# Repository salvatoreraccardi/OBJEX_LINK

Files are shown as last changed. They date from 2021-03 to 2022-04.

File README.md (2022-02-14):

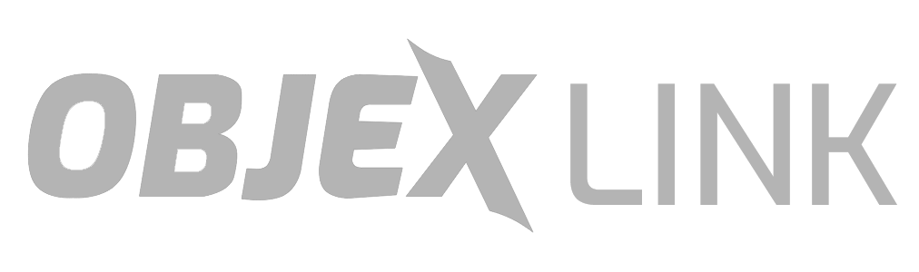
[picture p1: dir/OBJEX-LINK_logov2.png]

# OBJEX Link 

**OBJEX Link website:** https://objex.link/

**OBJEX Link Docs:** https://docs.objex.link/

**email:** info@objex.link 

**OBJEX Link Shop:** https://www.tindie.com/stores/objex/





**Youtube:** <br />
Project introduction - **OBJEX Link** [watch the video](https://www.youtube.com/watch?v=X29LyX-1ozA)

Assembly and testing - **Protoboard&Socket_v2.0** [watch the video](https://www.youtube.com/watch?v=N7MFNUX0_PA)

Assembly and testing - **OBJEX Link v1.6-C3:** [watch the video](https://www.youtube.com/watch?v=o9e5-9o4egI)

Assembly and testing - **OBJEX Link v1.6:** [watch the video](https://www.youtube.com/watch?v=haHsvLIlmms)

Assembly and testing - **OBJEX Link v1.5:** [watch the video](https://www.youtube.com/watch?v=wx3dR2j1C28)

Assembly and testing - **OBJEX Link v1.0:** [watch the video](https://www.youtube.com/watch?v=_4CofqktS38)

## What is OBJEX Link?
OBJEX Link is a modular IoT board. It is designed to develop **IoT devices** that are **easy to repair** and **recycle**. OBJEX Link is designed to meet a wide range of uses: **Smart Home & Cities, IIOT, Everyday things & Wearables, Predictive Maintenance, Agriculture Automation.**

OBJEX Link can also be used for **rapid prototyping, and developing research and robotics projects, with the right module you can extend the possible uses of the board.**

The compact form factor and board design ensure easy use and maintenance of the board. The architecture of OBJEX Link is composed of two parts, the first is the mainboard (OBJEX Link) and the second is the module allows for easy customization and interfacing with hardware compared to other IoT boards.

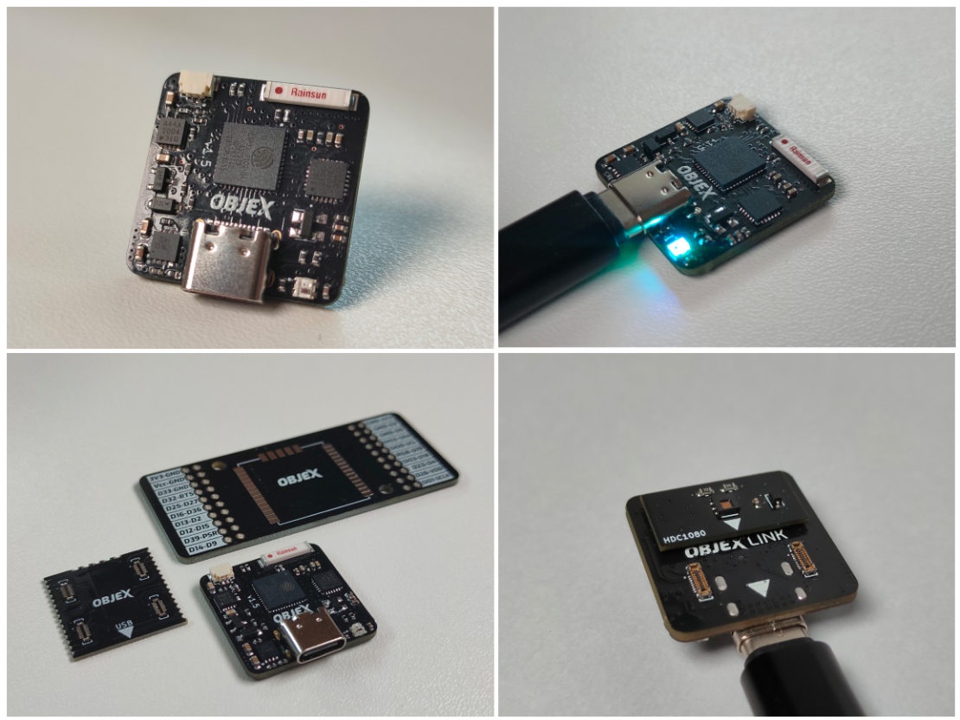
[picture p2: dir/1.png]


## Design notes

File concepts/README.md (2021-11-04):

# Concepts/Prototypes based on OBJEX Link

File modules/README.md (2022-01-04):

# OBJEX Modules
Modules are an essential element of OBJEX Link. In fact, they are the modules that allow OBJEX Link to detect the temperature, control an motor etc - *(like Arduino shields but smaller and more compact)*.

**Here are some features/components you can add with modules:**
- Sensors
- Relay 
- Motor driver(Stepper Motor, DC, LRA, ERM).
- OLED Display
- Convert slimstack connectors to larger connectors (type 2.54mm pitch connectors).
- A specific circuit (such as LoRa Module, PSRAM, PWM controller, etc).

## Types of modules
There are several form formats to ensure maximum customization.

| Type | Description | Size | PCB thickness | Connector | Connector Type | 3V3 | 5V | A |
|---|---|---|---|---|---|-----|----|---|
| M0 | Standard Module | 10x20mm | 0.8mm | 2 |  BM28B0 |  ✓ |  ✓  | 5 |
| M1 | Standard Module | 20x20mm | 0.8mm | 4 |  BM28B0 |  ✓ |  ✓  | 5 |
| M1E | With I2C EEPROM | 20x20mm | 0.8mm | 4 |  BM28B0 |  ✓ |  ✓  | 5 |

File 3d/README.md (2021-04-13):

## *NOTICE!*
**OBJEX Link is under development and optimization so some project files may vary over time.**

# OBJEX Modules
Modules are an essential element of OBJEX Link. In fact, they are the modules that allow OBJEX Link to detect the temperature, control an motor etc - *(like Arduino shields but smaller and more compact)*.

**Here are some features/components you can add with modules:**

- Sensors
- Relay 
- Motor driver(Stepper Motor, DC, LRA, ERM).
- OLED Display
- Convert slimstack connectors to larger connectors (type 2.54mm pitch connectors).
- A specific circuit (such as LoRa Module, PSRAM, PWM controller, etc).

## Types of modules
There are several form formats to ensure maximum customization.

| Type | Description | Size | PCB thickness | Connector | Connector Type | 3V3 | 5V | A |
|---|---|---|---|---|---|-----|----|---|
| M0 | Standard Module | 10x20mm | 0.8mm | 2 |  BM28B0 |  ✓ |  ✓  | 5 |
| M1 | Standard Module | 20x20mm | 0.8mm | 4 |  BM28B0 |  ✓ |  ✓  | 5 |

## List of available modules

| Module Type | Module Name | Description | Size | Version | Designer | Buy | Example of use  |
|---|---|---|---|---|---|---|---|
| M1 | Button | Button with 4 leds | 20x20mm | 1.0 | Salvatore Raccardi | Not available | IoT Button|
| M0 | MPU6050 | Sensor - Gyroscope| 10x20mm | 1.0 | Salvatore Raccardi | Not available | - |
| M0 | HDC1080 | Sensor - Temperature/Humidity| 10x20mm | 1.0 | Salvatore Raccardi | Not available | Weather station |

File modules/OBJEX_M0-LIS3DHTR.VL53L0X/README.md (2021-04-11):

## COPYRIGHT
Copyright CERN 2020.

This source describes Open Hardware and is licensed under the CERN-OHLW v2

You may redistribute and modify this documentation and make products
using it under the terms of the CERN-OHL-W v2 (https:/cern.ch/cern-ohl).
This documentation is distributed WITHOUT ANY EXPRESS OR IMPLIED
WARRANTY, INCLUDING OF MERCHANTABILITY, SATISFACTORY QUALITY
AND FITNESS FOR A PARTICULAR PURPOSE. Please see the CERN-OHL-W v2
for applicable conditions.

Source location: https://www.ohwr.org/project/wr-switch-hw

As per CERN-OHL-W v2 section 4.1, should You produce hardware based on
these sources, You must maintain the Source Location visible on the
external case of the White Rabbit switch or other product you make using
this documentation.

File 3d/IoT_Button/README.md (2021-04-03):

# OBJEX Link - 3D Case
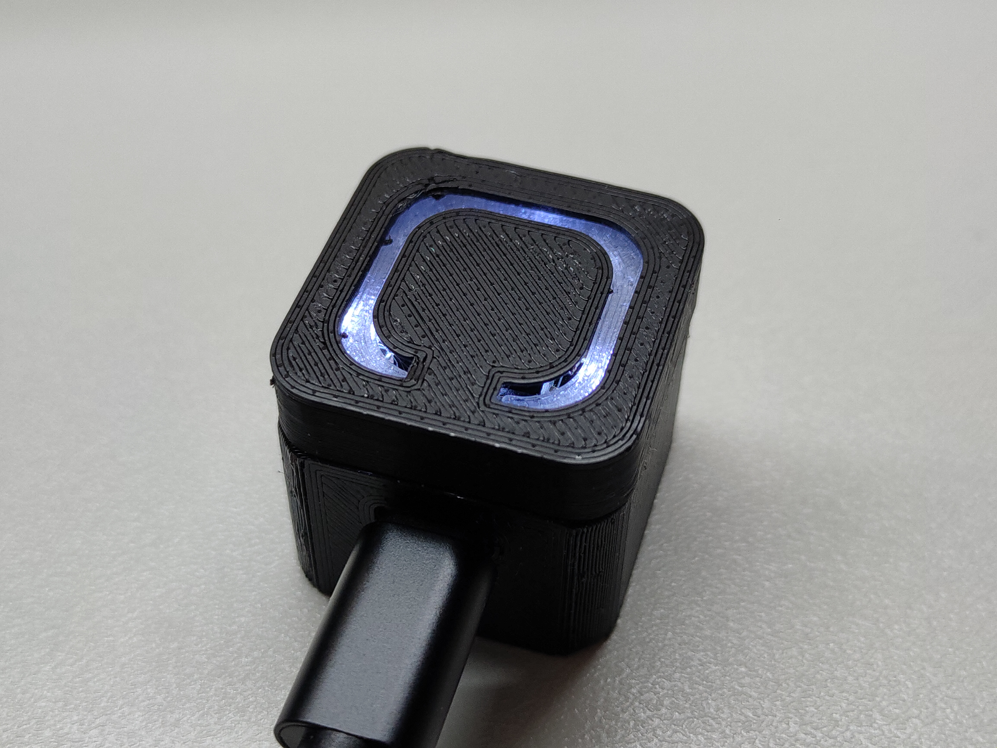
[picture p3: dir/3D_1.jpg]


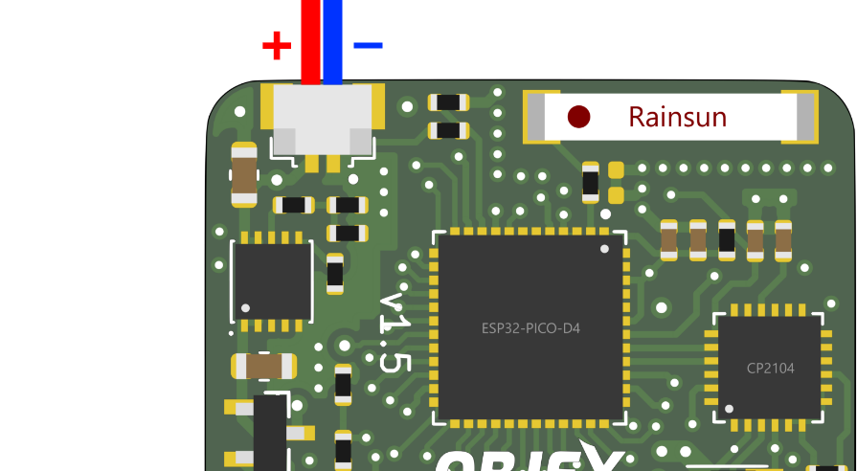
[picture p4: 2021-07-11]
dir/pinout_2.png

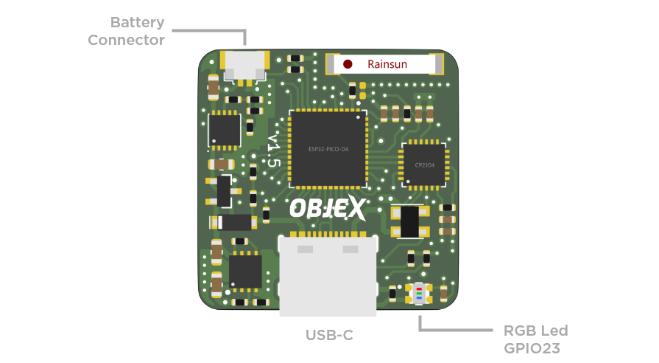
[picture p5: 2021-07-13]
dir/pinout1.png

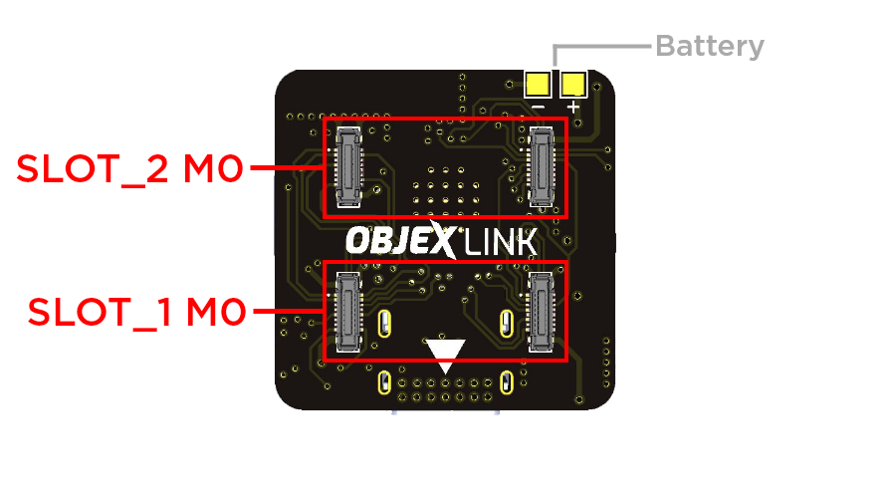
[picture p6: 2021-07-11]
dir/pinout_3.png

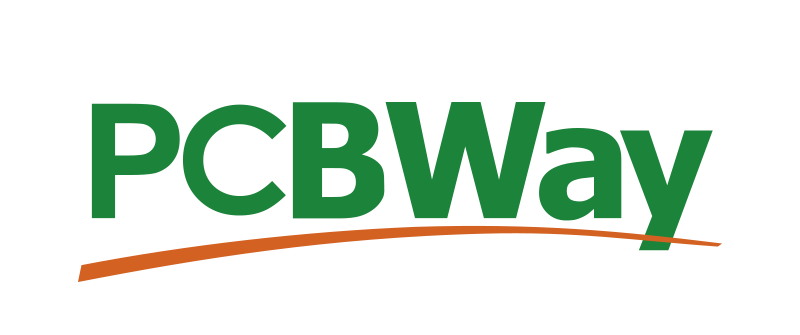
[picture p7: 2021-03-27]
dir/pcbway.png

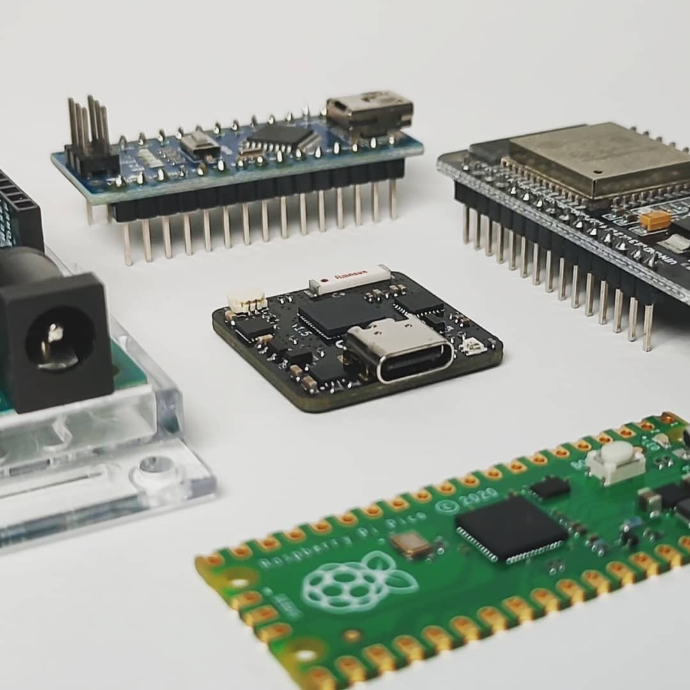
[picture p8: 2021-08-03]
dir/OBJEXLinkvsboards.jpg

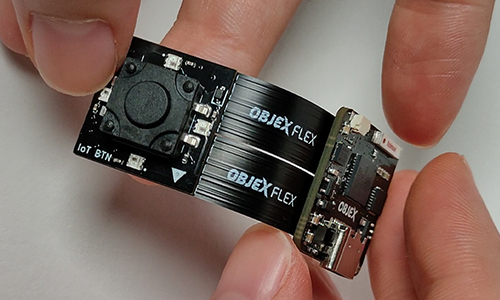
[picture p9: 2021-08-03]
dir/Flex_6.jpg

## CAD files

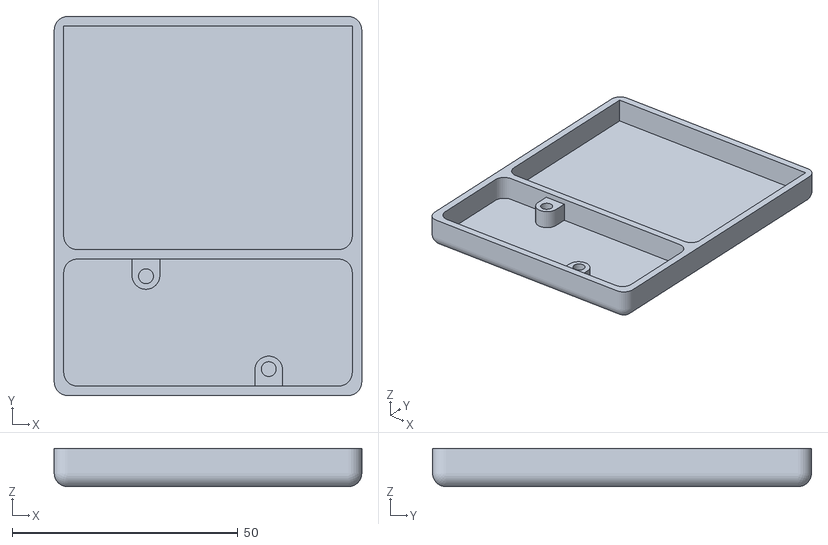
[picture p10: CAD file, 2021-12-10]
3d/Cover_2.54Board-v2.0/OBJEXLink_Cover_Pro.stl
68.1 x 83.9 x 8.50

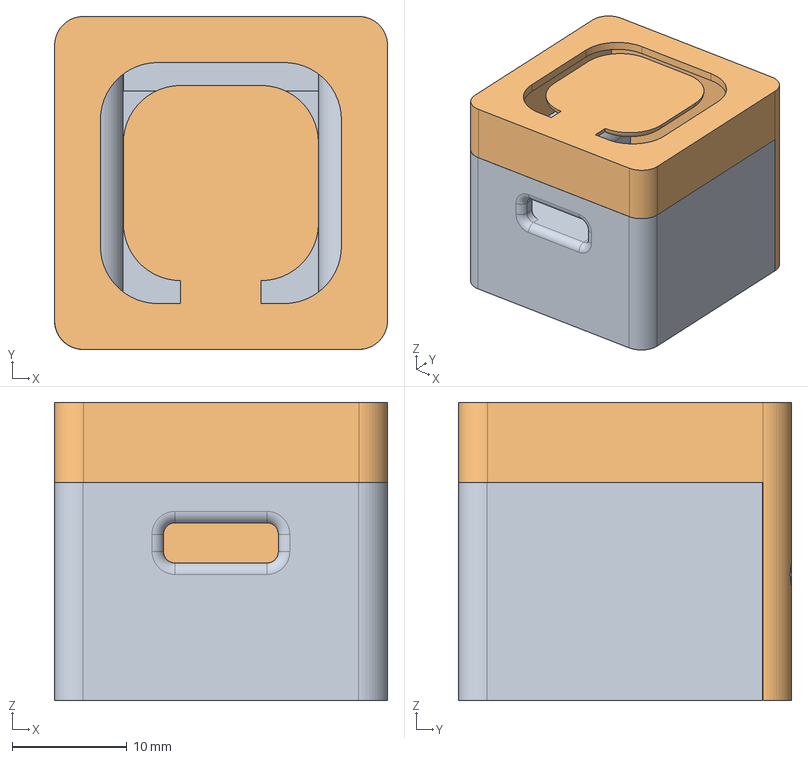
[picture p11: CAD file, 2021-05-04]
3d/IoT_Button/beta-2.0/OBJEX_LINK-IoT_Btn.step
29.0 x 29.0 x 26.0 mm

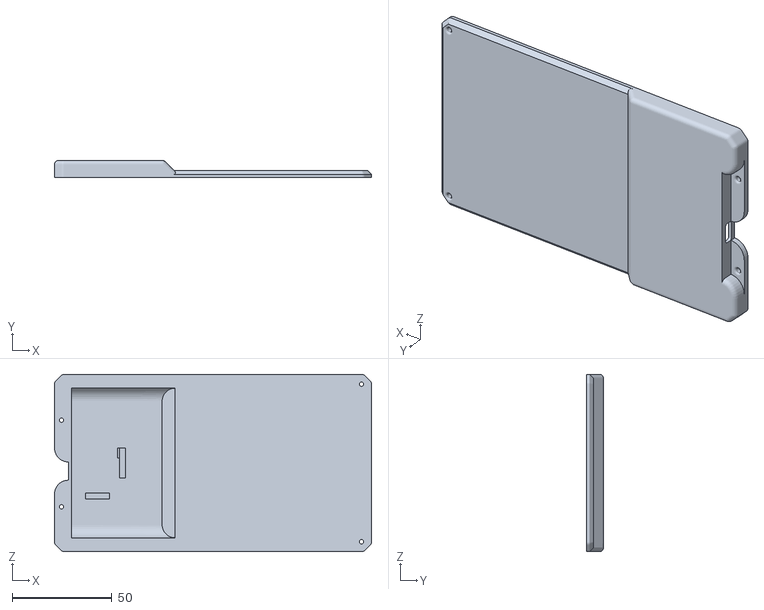
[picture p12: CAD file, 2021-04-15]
3d/Led_Spotlight-v1.0/Back Cover.stl
159.0 x 8.50 x 89.0

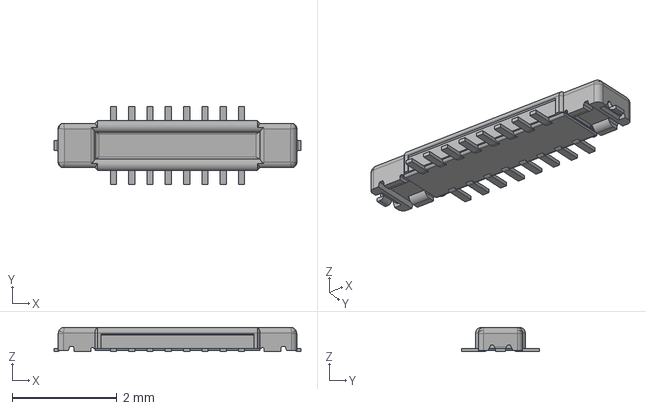
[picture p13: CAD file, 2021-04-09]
KiCad_lib/SlimStack Connector/BM28-16DP.stp
4.72 x 1.50 x 0.465 mm

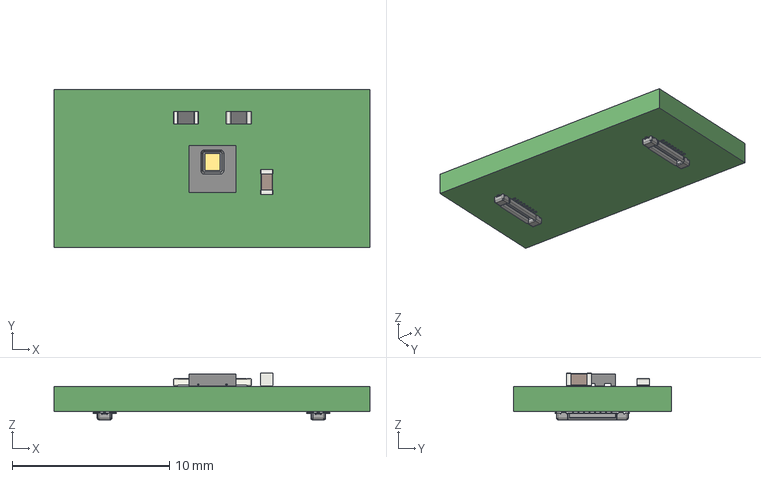
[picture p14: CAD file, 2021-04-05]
modules/OBJEX_M0-HDC1080/OBJEX_M0-HDC1080.step
20.1 x 10.0 x 2.97 mm

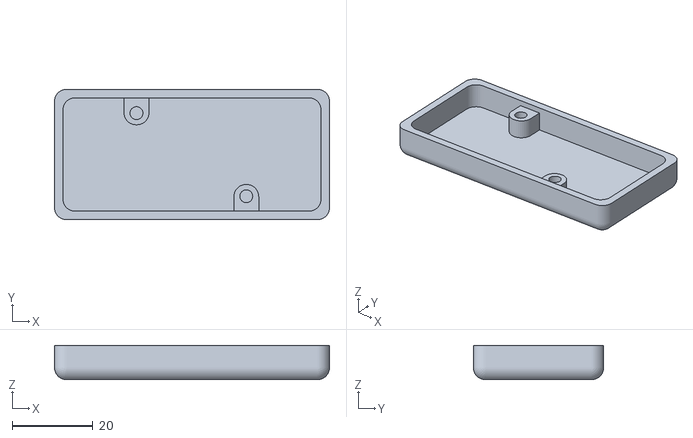
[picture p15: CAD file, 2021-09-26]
3d/Cover_2.54Board-v2.0/V2.1coverOBJEXLink.stl
68.1 x 32.3 x 8.50

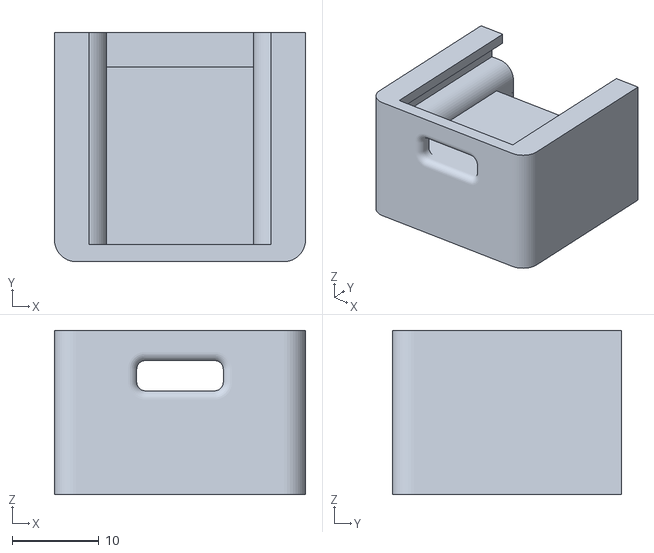
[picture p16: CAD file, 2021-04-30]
3d/IoT_Button/beta-2.0/Master.stl
29.0 x 26.5 x 19.0

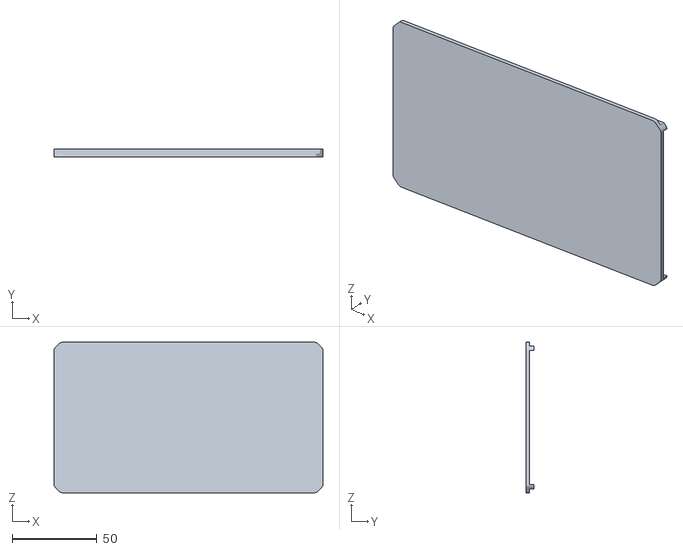
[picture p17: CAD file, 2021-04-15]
3d/Led_Spotlight-v1.0/Lux-Plate.stl
159.0 x 4.60 x 89.0

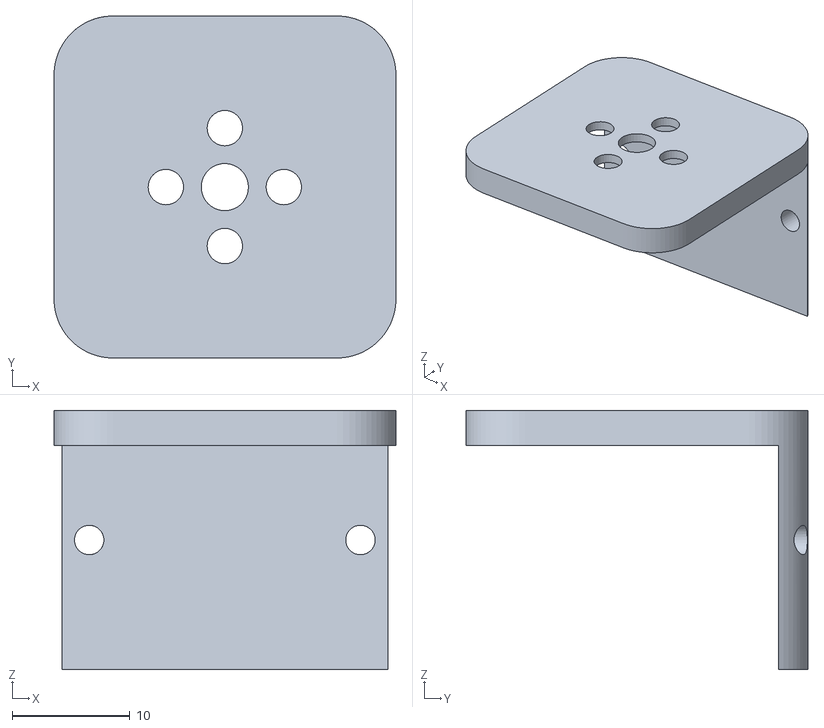
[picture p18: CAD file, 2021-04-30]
3d/IoT_Button/beta-2.0/HDC1080-Top.stl
29.0 x 29.0 x 22.0

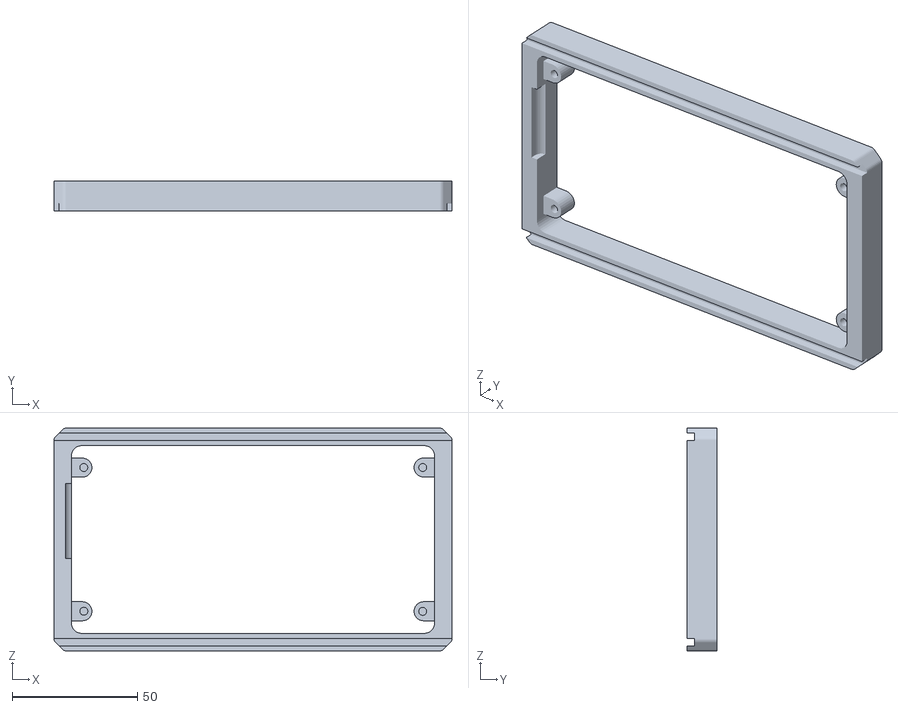
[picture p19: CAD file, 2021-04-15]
3d/Led_Spotlight-v1.0/Frame.stl
159.0 x 12.0 x 89.0

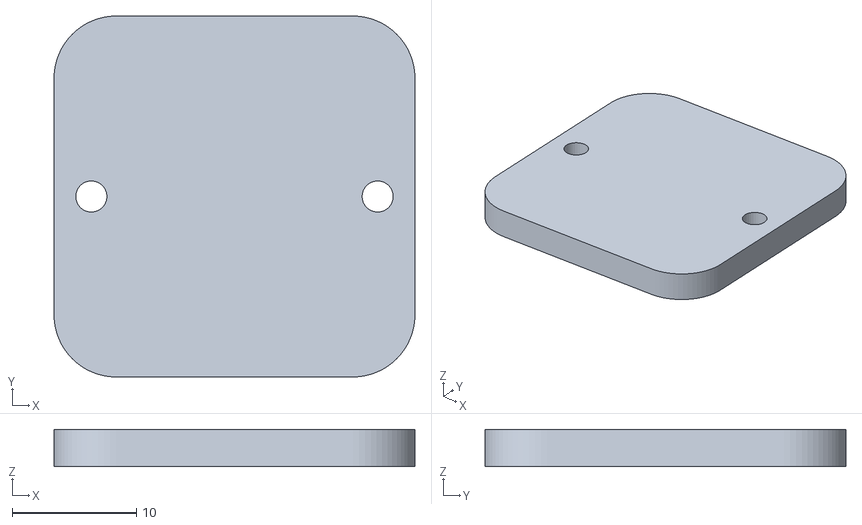
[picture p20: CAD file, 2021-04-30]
3d/IoT_Button/beta-2.0/Bottom.stl
29.0 x 29.0 x 3.00

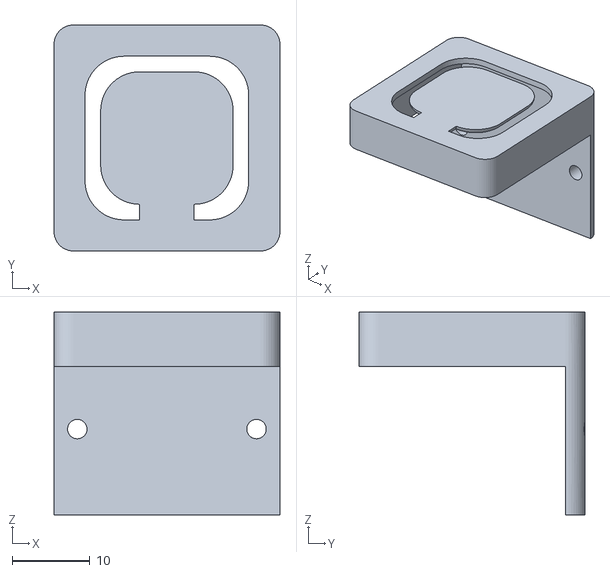
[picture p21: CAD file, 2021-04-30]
3d/IoT_Button/beta-2.0/BTN-Top.stl
29.0 x 29.0 x 26.0

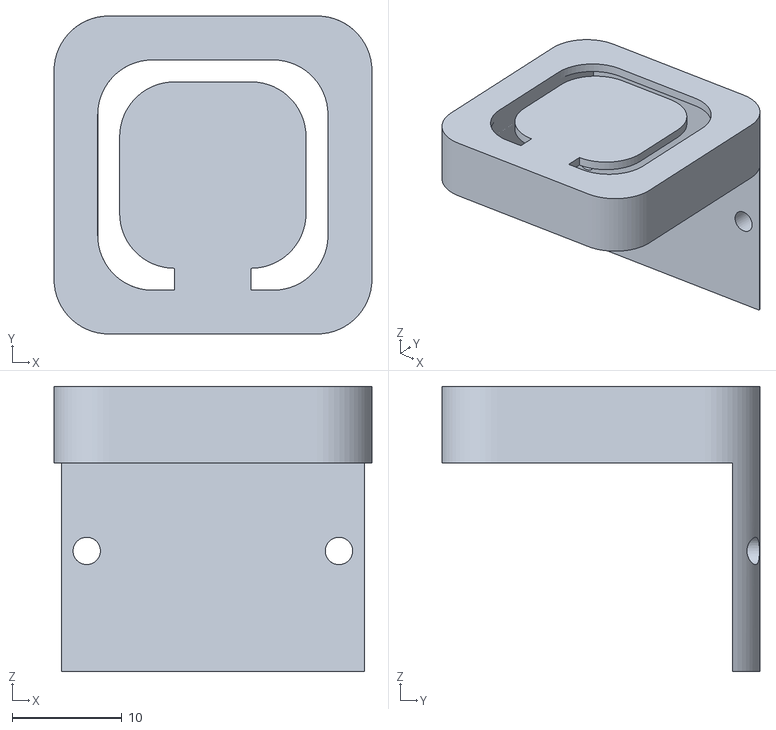
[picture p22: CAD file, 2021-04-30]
3d/IoT_Button/beta-2.0/Top.stl
29.0 x 29.0 x 26.0

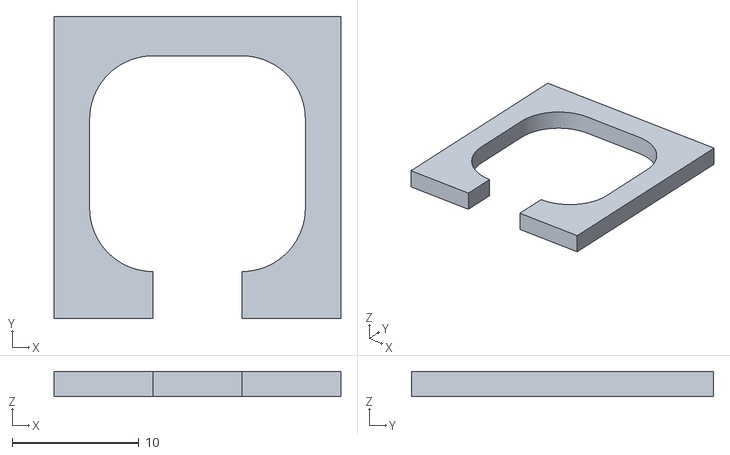
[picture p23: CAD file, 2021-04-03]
3d/IoT_Button/beta-2.0/Top_Glass.stl
22.6 x 23.8 x 2.00

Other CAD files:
3d/Cover_2.54Board-v2.0/V2coverOBJEXLink.stl
3d/IoT_Button/beta-1.0/Master.stl
3d/IoT_Button/beta-1.0/HDC1080-Top.stl
3d/IoT_Button/beta-1.0/BTN-Top.stl

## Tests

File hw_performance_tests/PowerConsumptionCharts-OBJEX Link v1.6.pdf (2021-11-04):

# Power Consumption Charts

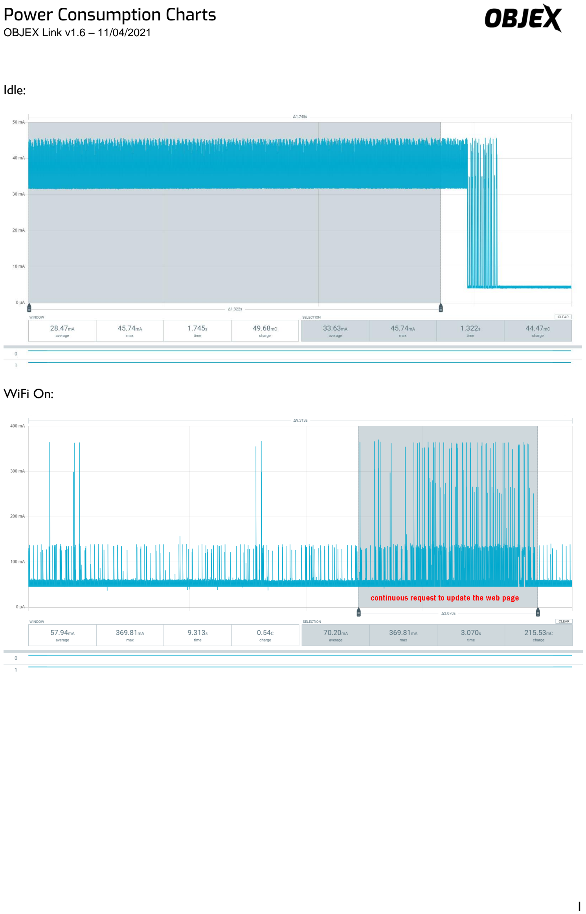
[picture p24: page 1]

OBJEX Link v1.6 – 11/04/2021

Idle:

WiFi On:

Bluetooth On:

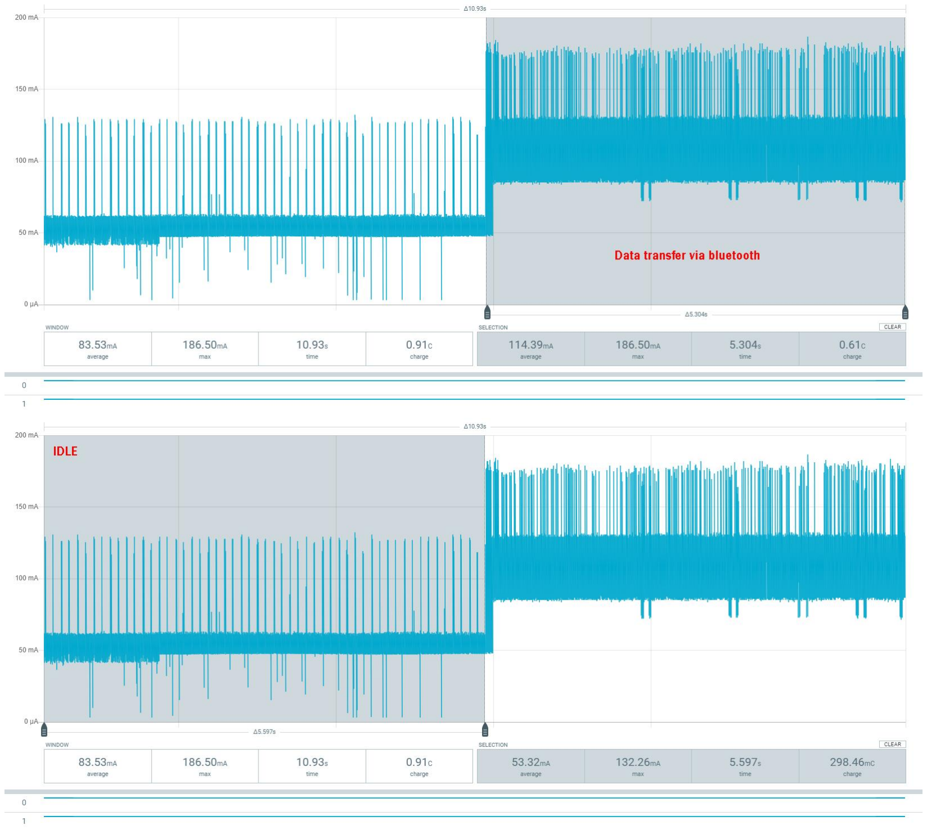
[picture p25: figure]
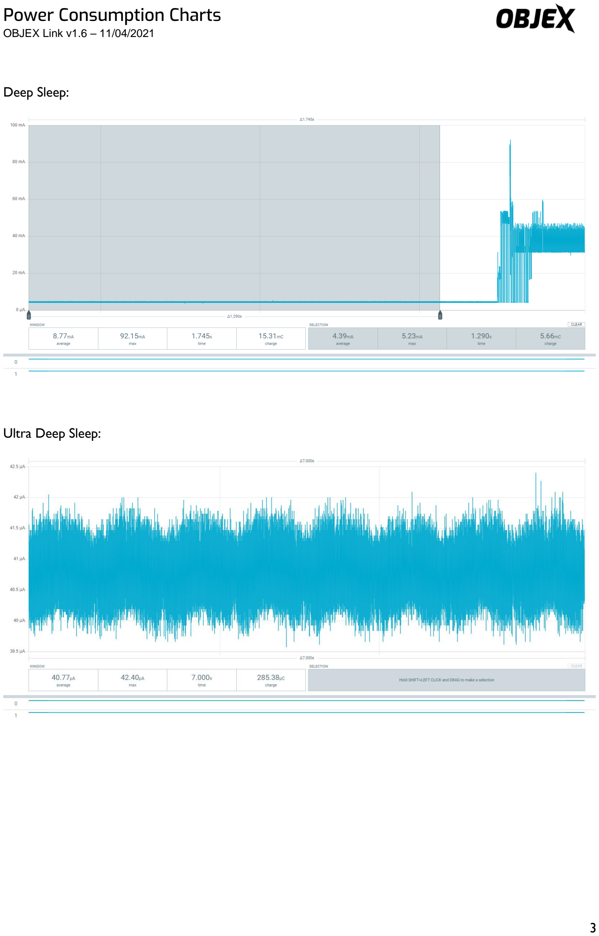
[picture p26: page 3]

Deep Sleep:

Ultra Deep Sleep:

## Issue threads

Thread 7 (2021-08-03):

Broken Trello link

zaosoula, 2021-08-03:
Hello, the Trello link in the footer of the wiki is broken

salvatoreraccardi, 2021-08-03:
Yes, you are right, I am fixing the board on Trello. I'll let you know when it's available.

Closed 2021-08-03.

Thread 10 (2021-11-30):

native USB

Aightech, 2021-11-30:
Hi there,
Thank you very much for sharing your great work on github!

I looked at your OBJEX Link v1.6-C3 RISC-V schematics and I realised you were using a cp2102 for the USB communication. Is there a particular reason you did not use the native USB of the esp32-C3 ?

Thanks again!

salvatoreraccardi, 2021-11-30:
@Aightech Hi, thank you for your question. I have already designed v1.7-C3 without the CP2102N and some improvements. Next week I will get the PCBs delivered👍

Aightech, 2021-12-01:
Wonderful, can't wait to see it then! 😁

salvatoreraccardi, 2021-12-29:
https://github.com/salvatoreraccardi/OBJEX_LINK/tree/main/boards/OBJEX_LINK-Rev1.7-C3_RISC-V

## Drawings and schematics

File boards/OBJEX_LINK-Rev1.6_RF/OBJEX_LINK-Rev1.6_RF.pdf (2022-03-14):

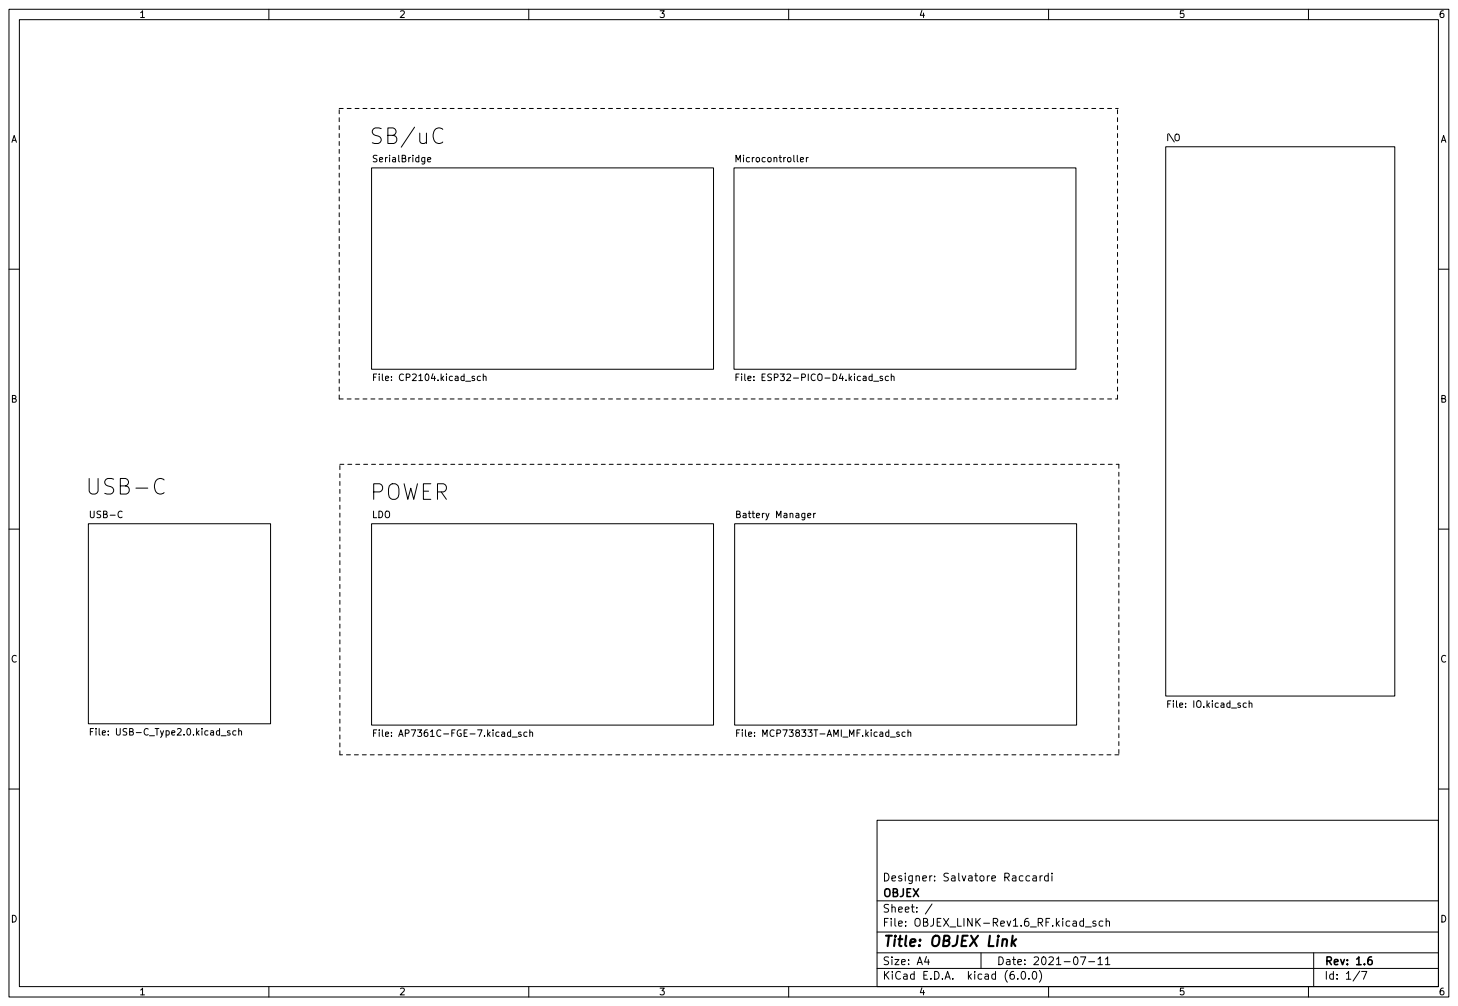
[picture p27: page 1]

Microcontroller File: ESP32-PICO-D4.kicad_sch SerialBridge File: CP2104.kicad_sch

File: OBJEX_LINK-Rev1.6_RF.kicad_sch Sheet: / OBJEX Designer: Salvatore Raccardi

Id: 1/7 Title: OBJEX Link

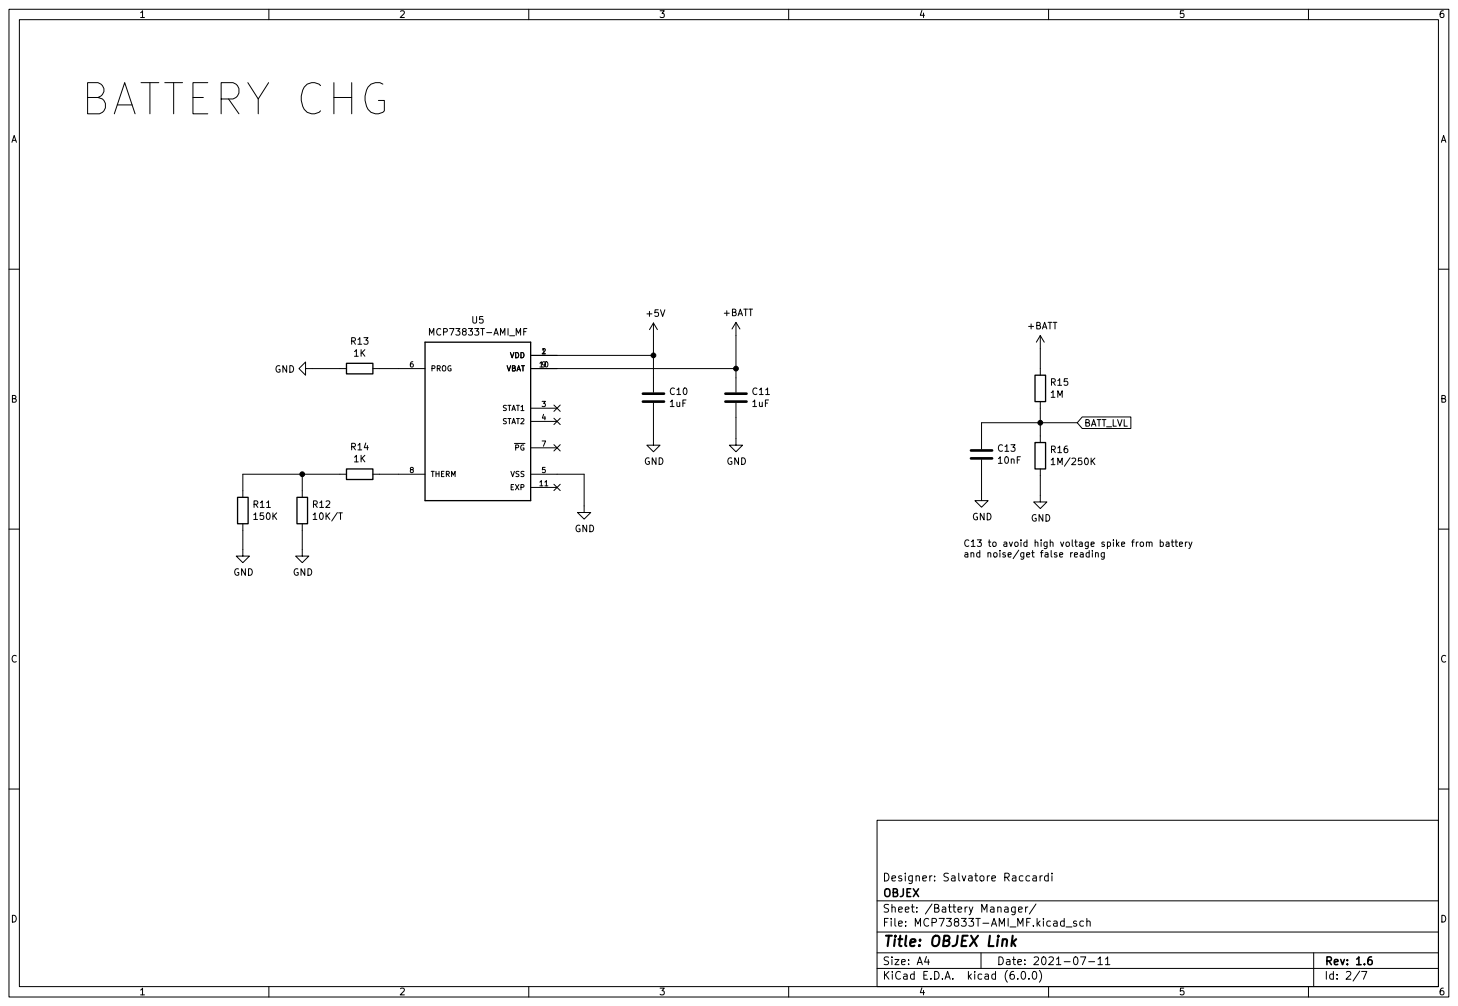
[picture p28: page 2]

BATT_LVL C13 to avoid high voltage spike from battery

and noise/get false reading

File: MCP73833T-AMI_MF.kicad_sch
Id: 2/7 Title: OBJEX Link

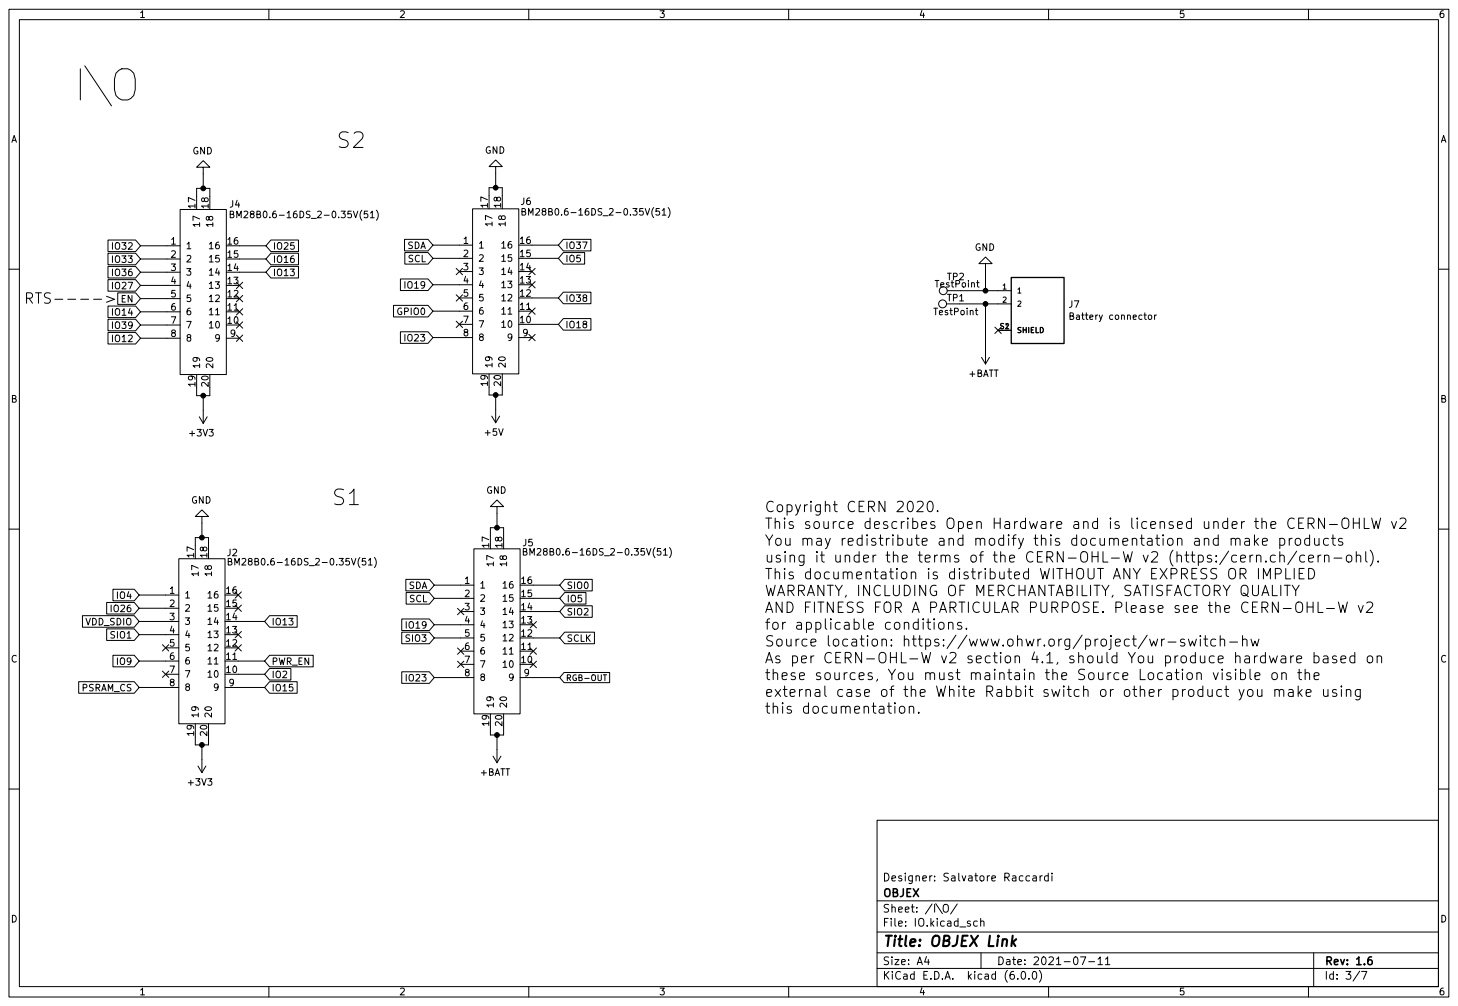
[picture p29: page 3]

Copyright CERN 2020.
This source describes Open Hardware and is licensed under the CERN-OHLW v2
You may redistribute and modify this documentation and make products
using it under the terms of the CERN-OHL-W v2 (https:/cern.ch/cern-ohl).
This documentation is distributed WITHOUT ANY EXPRESS OR IMPLIED
WARRANTY, INCLUDING OF MERCHANTABILITY, SATISFACTORY QUALITY
AND FITNESS FOR A PARTICULAR PURPOSE. Please see the CERN-OHL-W v2
for applicable conditions.
Source location: https://www.ohwr.org/project/wr-switch-hw
As per CERN-OHL-W v2 section 4.1, should You produce hardware based on
these sources, You must maintain the Source Location visible on the
external case of the White Rabbit switch or other product you make using
this documentation.

Id: 3/7 Title: OBJEX Link

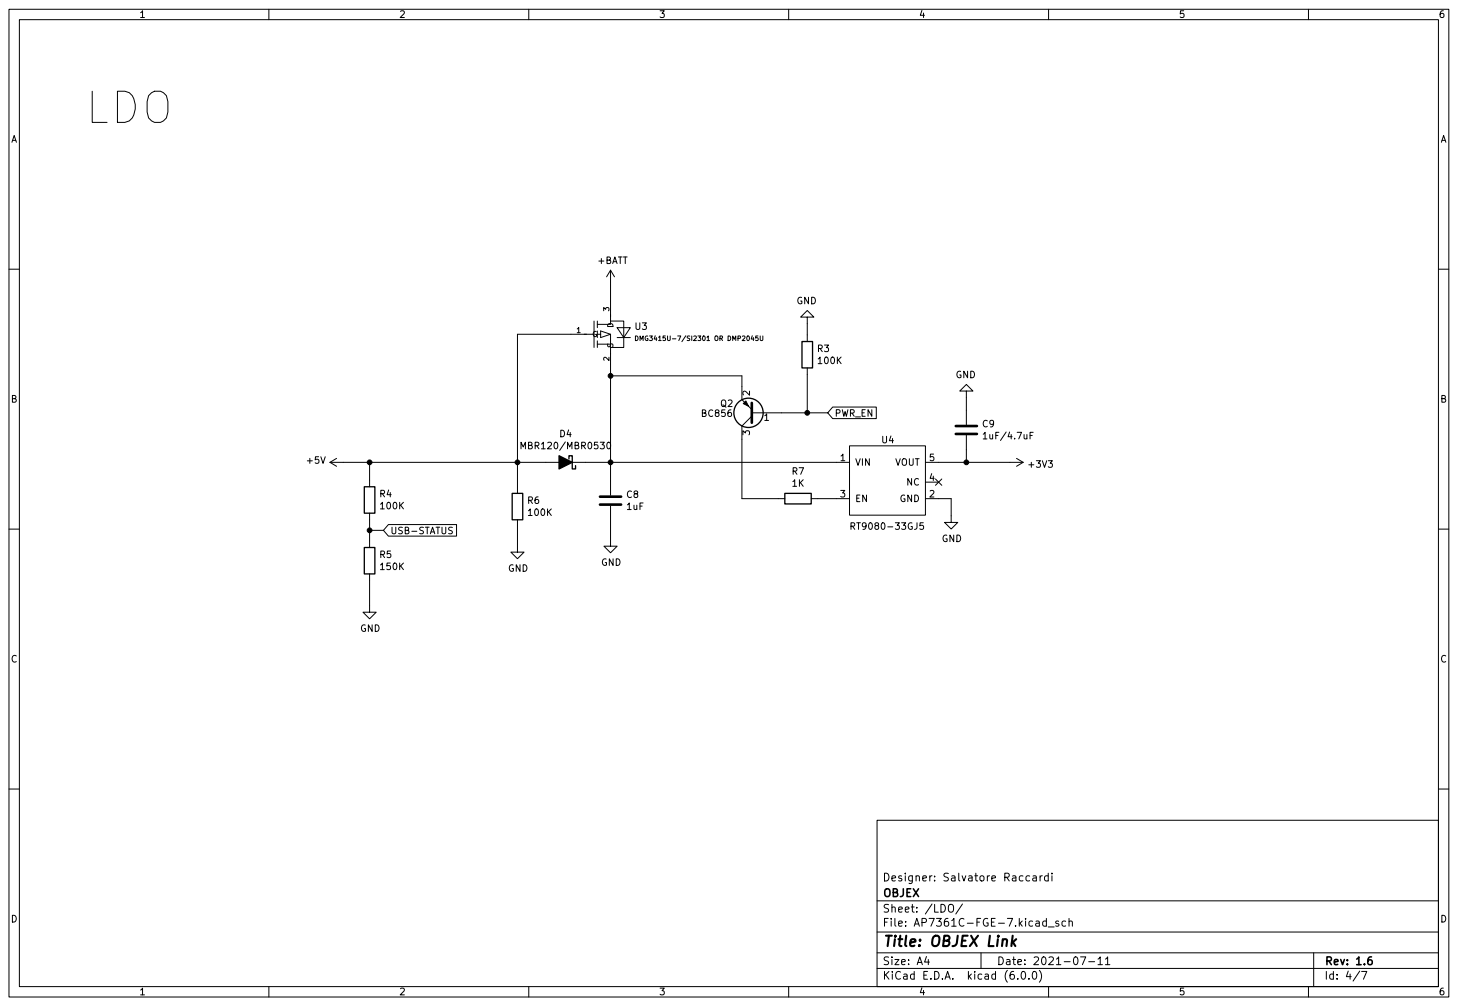
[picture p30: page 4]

File: AP7361C-FGE-7.kicad_sch Sheet: /LDO/ OBJEX Designer: Salvatore Raccardi

Id: 4/7 Title: OBJEX Link

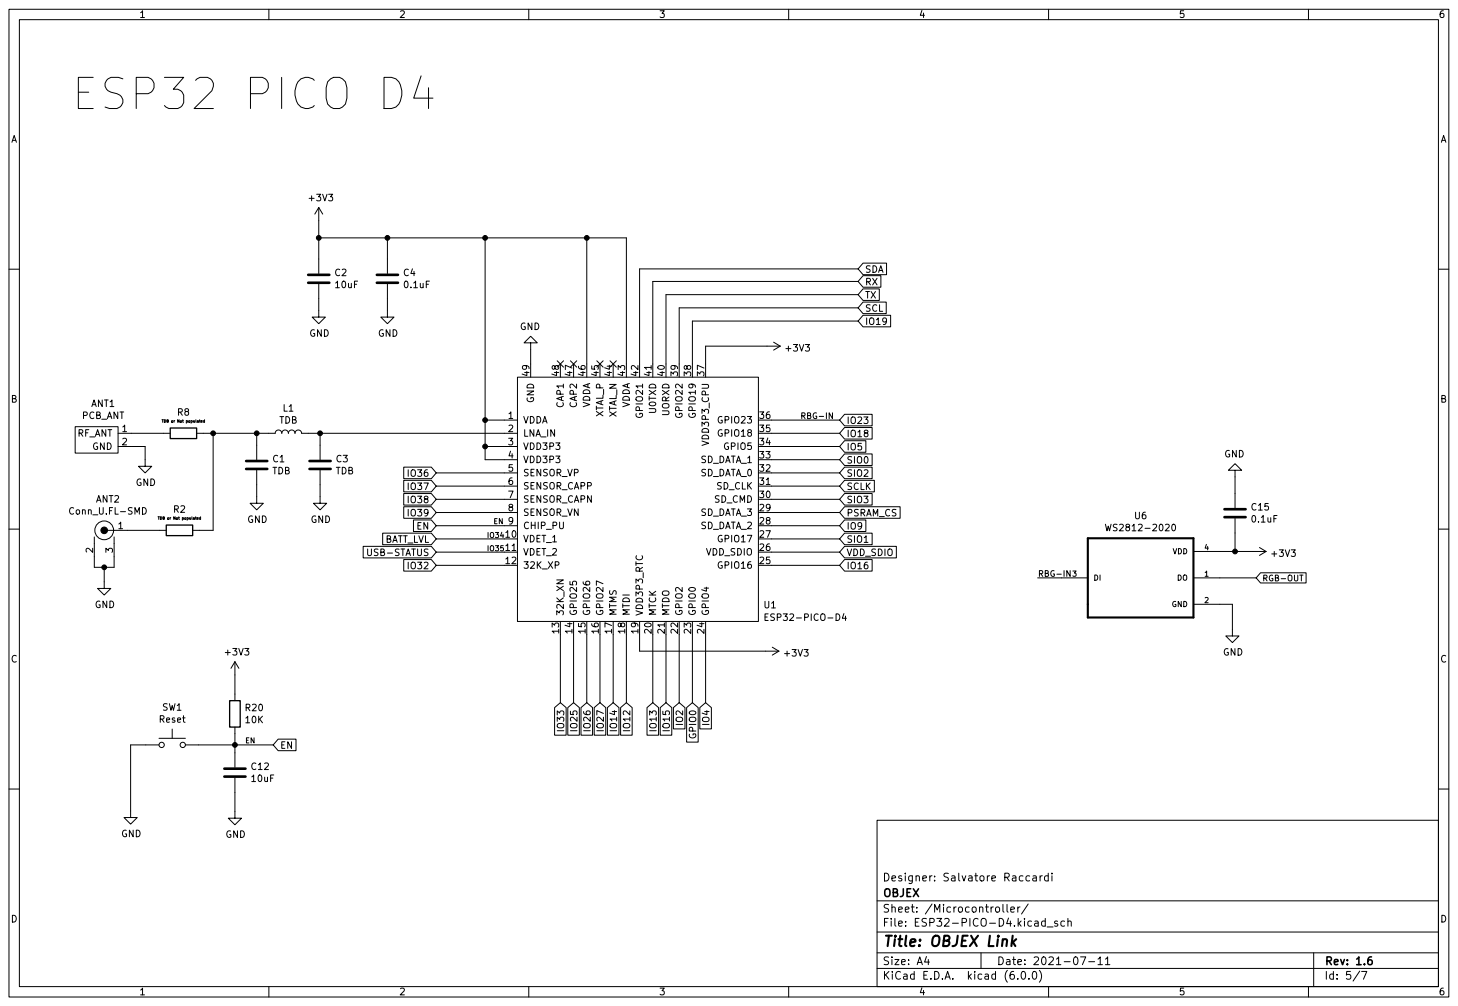
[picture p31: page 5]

TDB or Not populated 1

File: ESP32-PICO-D4.kicad_sch Sheet: /Microcontroller/ OBJEX Designer: Salvatore Raccardi

Id: 5/7 Title: OBJEX Link

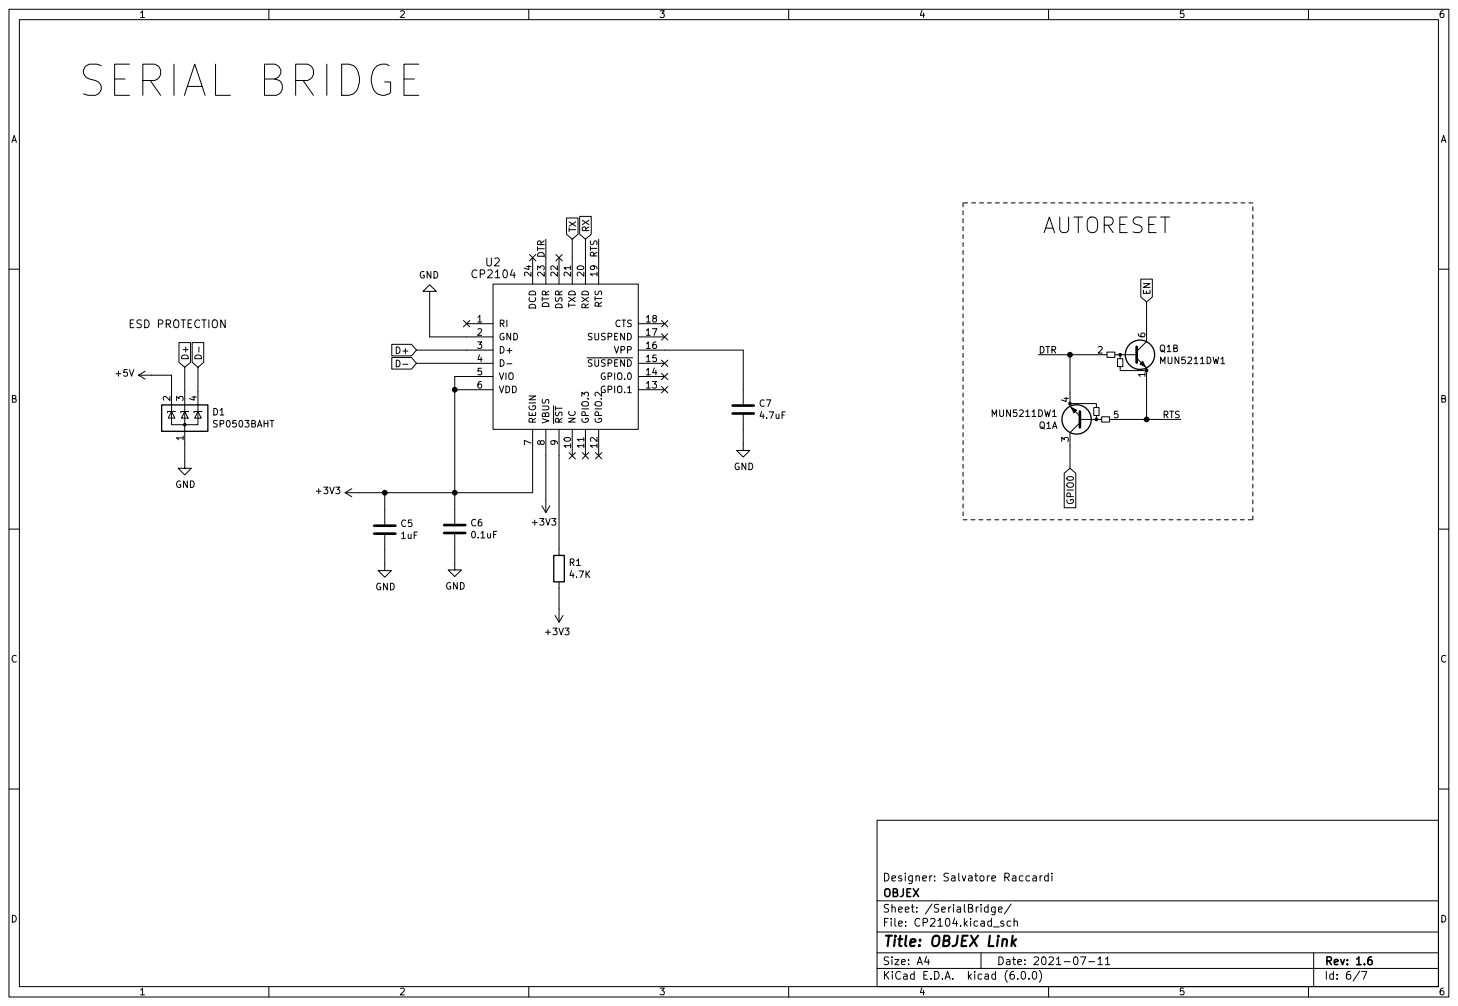
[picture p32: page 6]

ESD PROTECTION SERIAL BRIDGE

Sheet: /SerialBridge/ OBJEX Designer: Salvatore Raccardi

File: CP2104.kicad_sch
Id: 6/7 Title: OBJEX Link

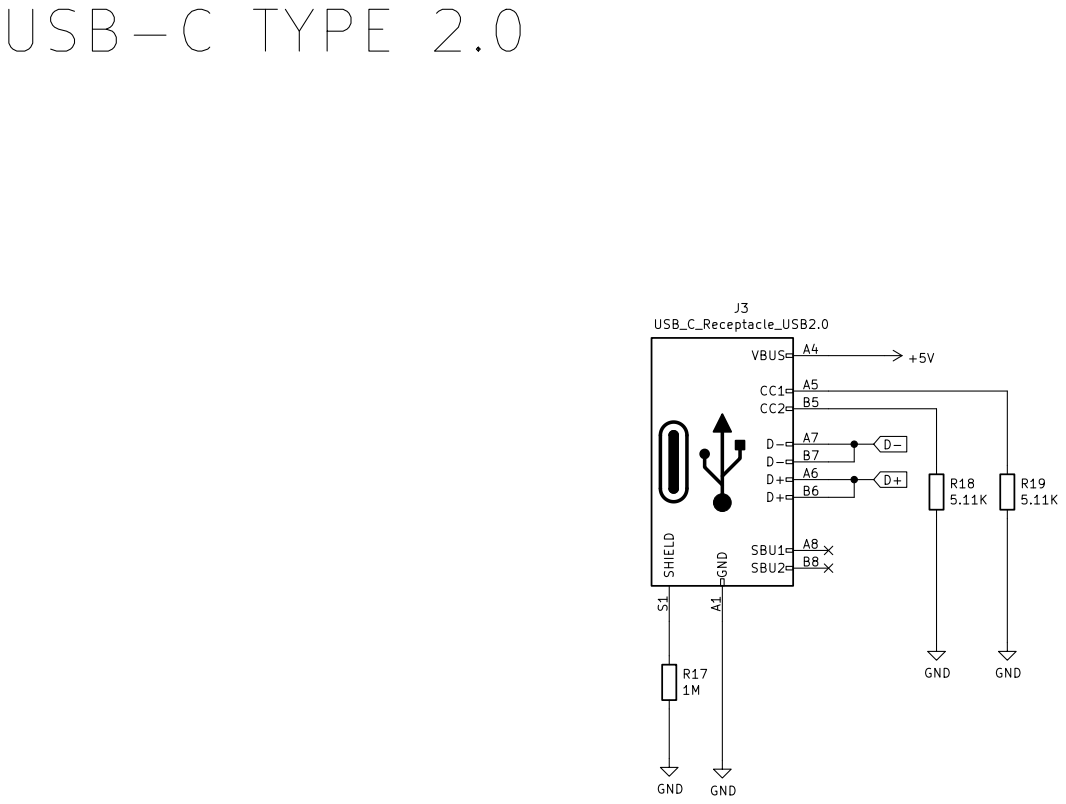
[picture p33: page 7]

D- D+ USB-C TYPE 2.0
File: USB-C_Type2.0.kicad_sch Sheet: /USB-C/ OBJEX Designer: Salvatore Raccardi R18

Id: 7/7 Title: OBJEX Link

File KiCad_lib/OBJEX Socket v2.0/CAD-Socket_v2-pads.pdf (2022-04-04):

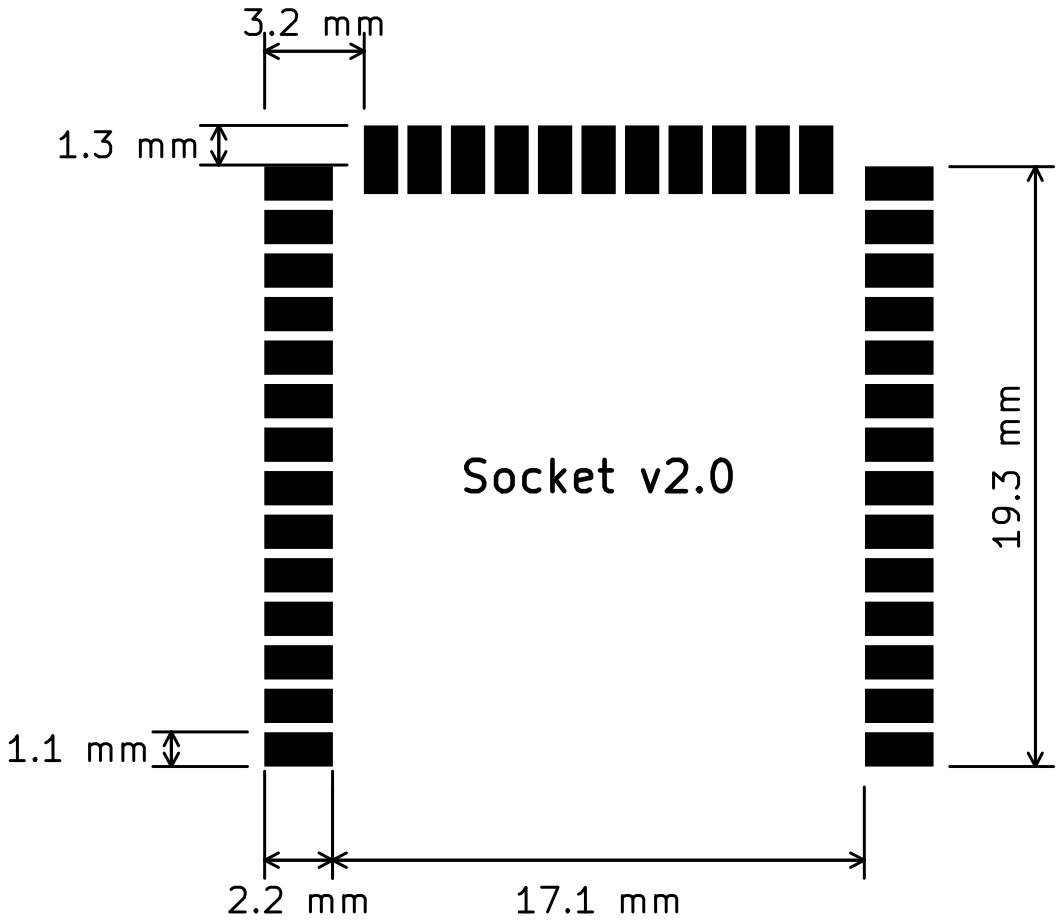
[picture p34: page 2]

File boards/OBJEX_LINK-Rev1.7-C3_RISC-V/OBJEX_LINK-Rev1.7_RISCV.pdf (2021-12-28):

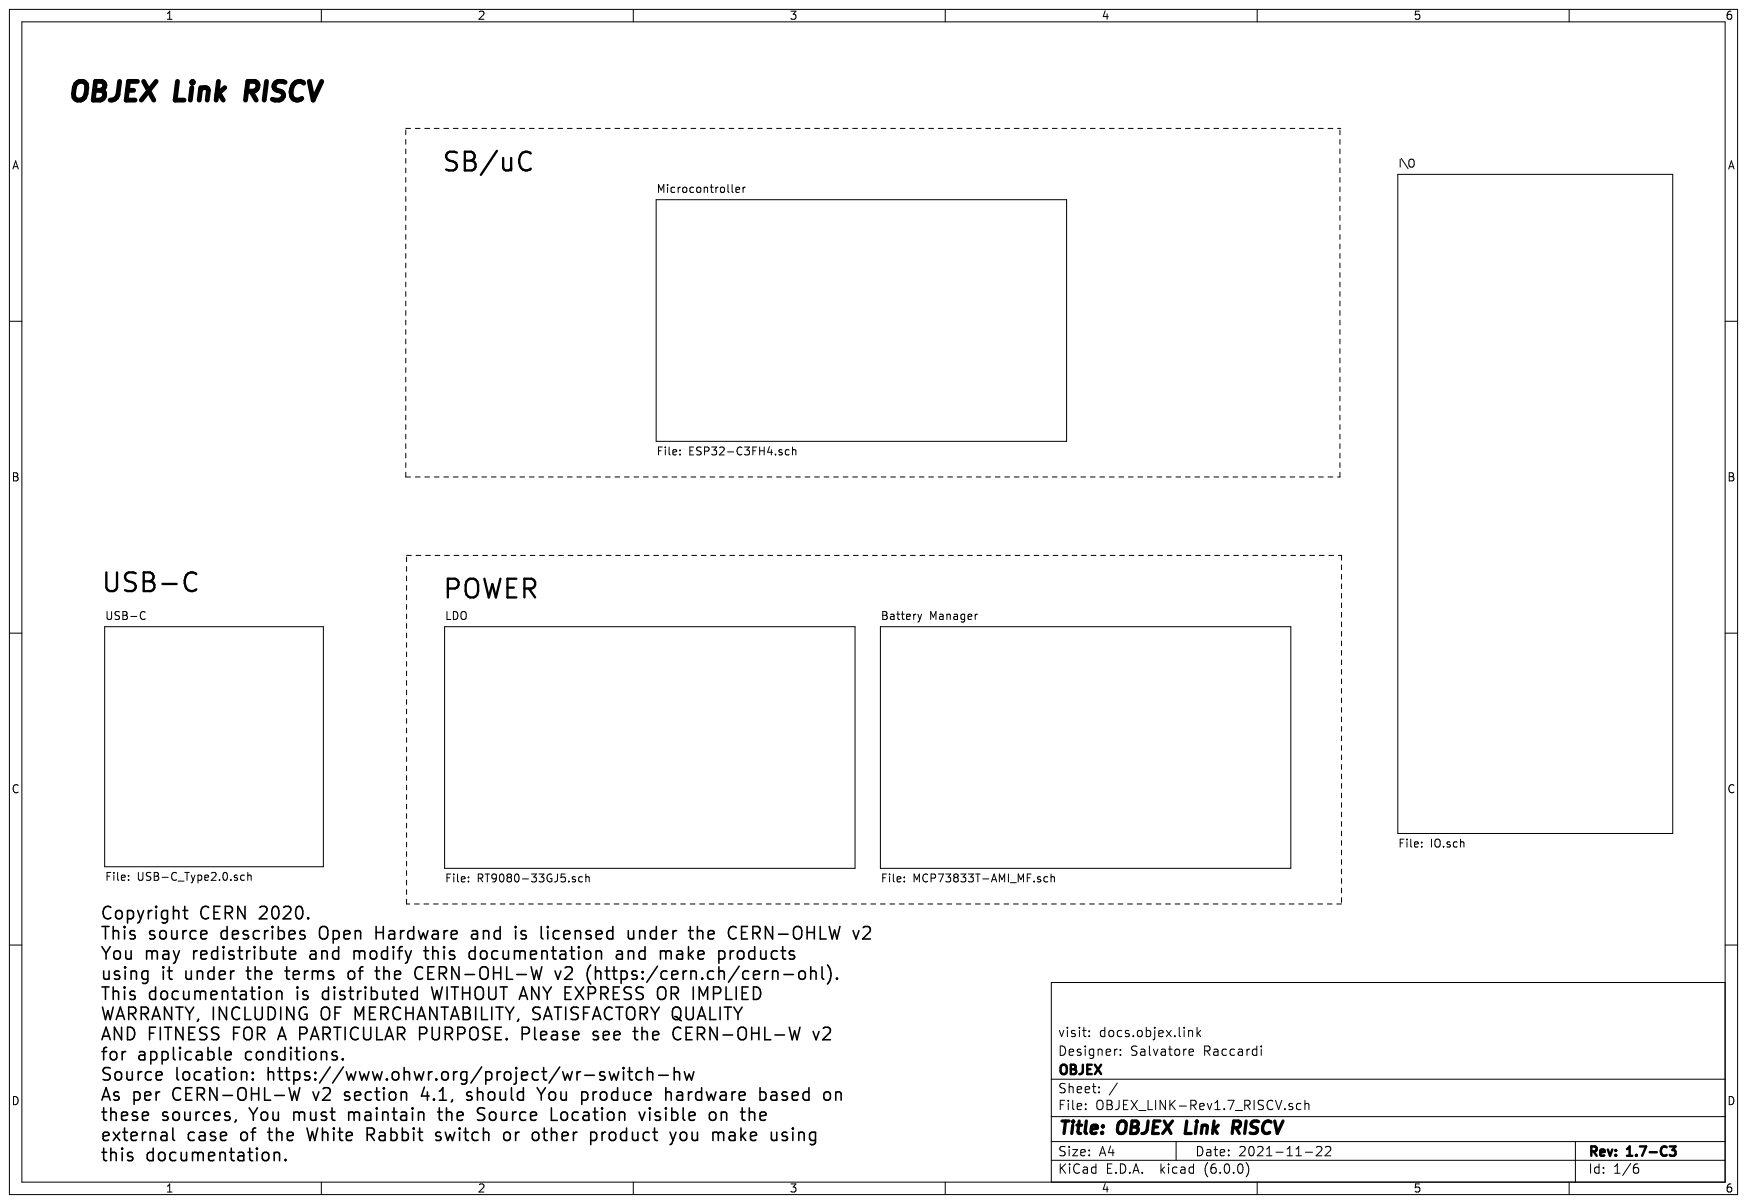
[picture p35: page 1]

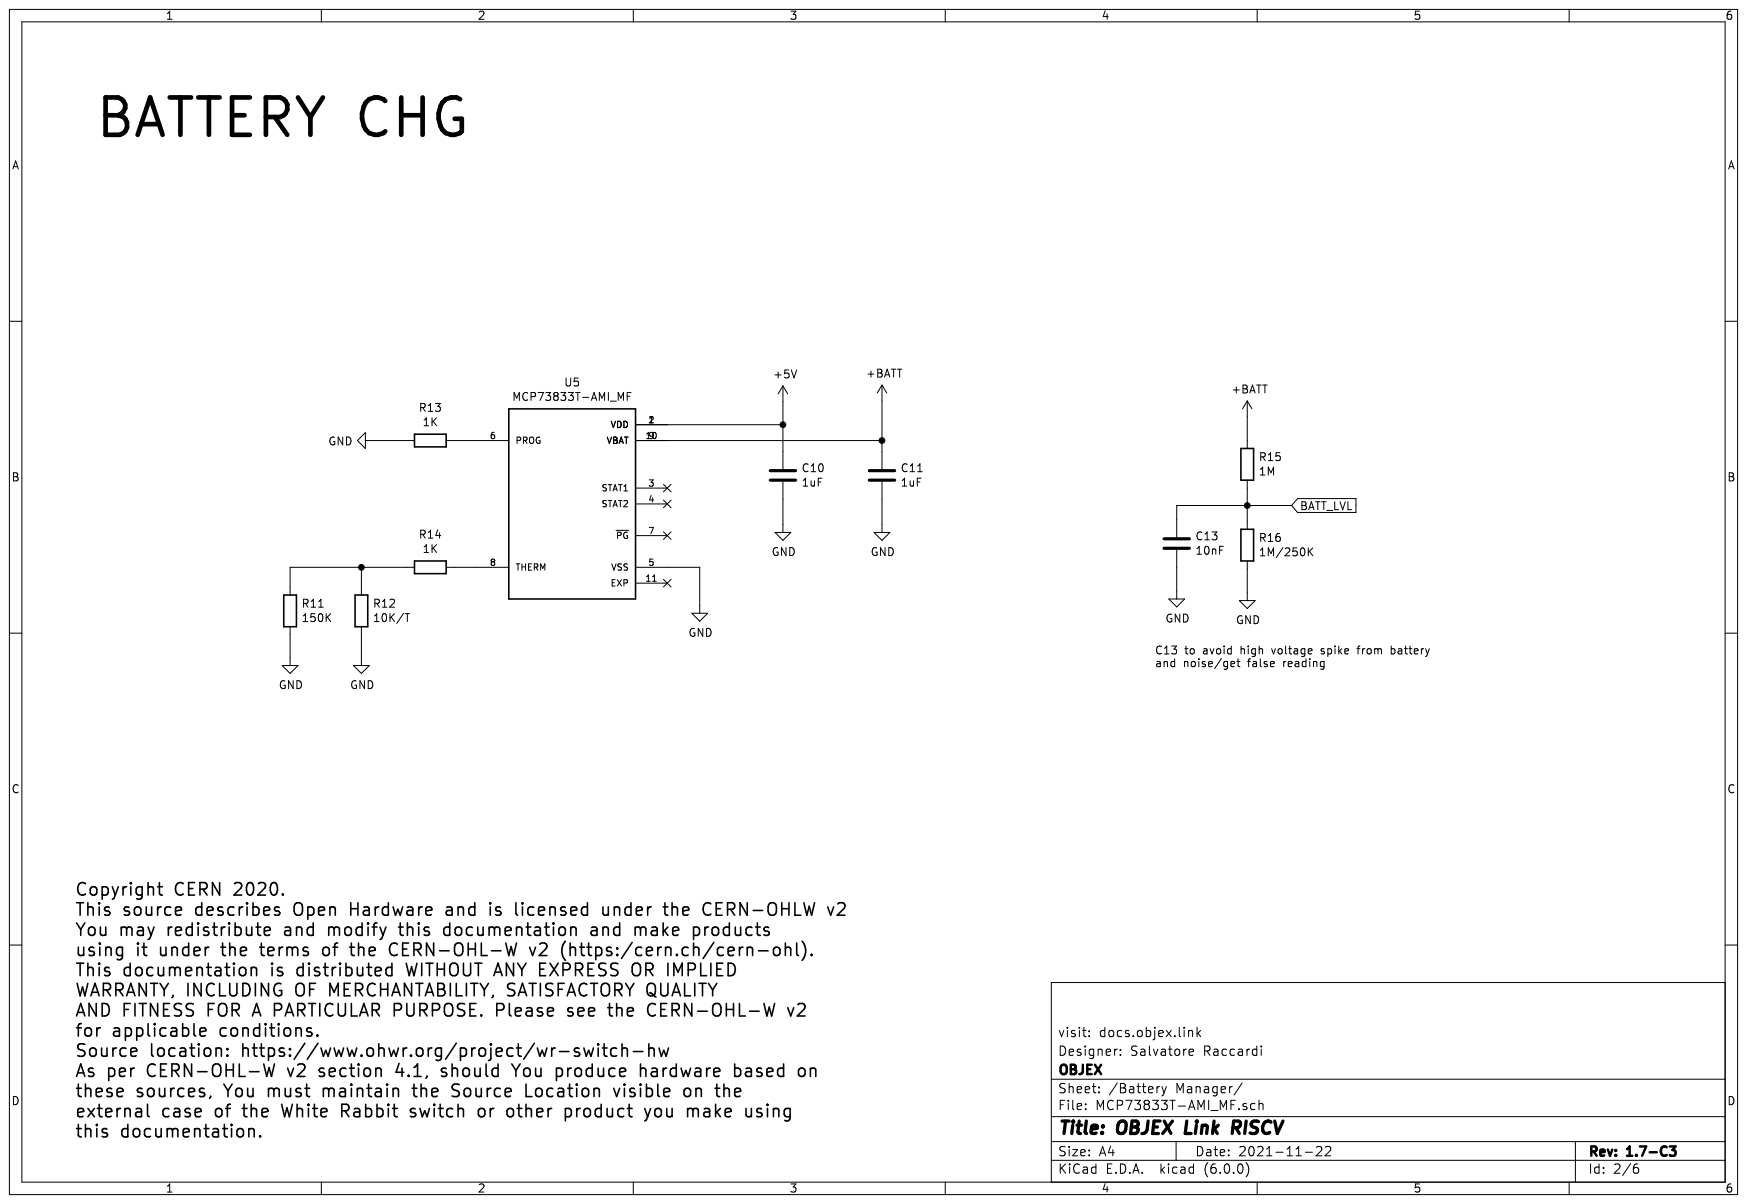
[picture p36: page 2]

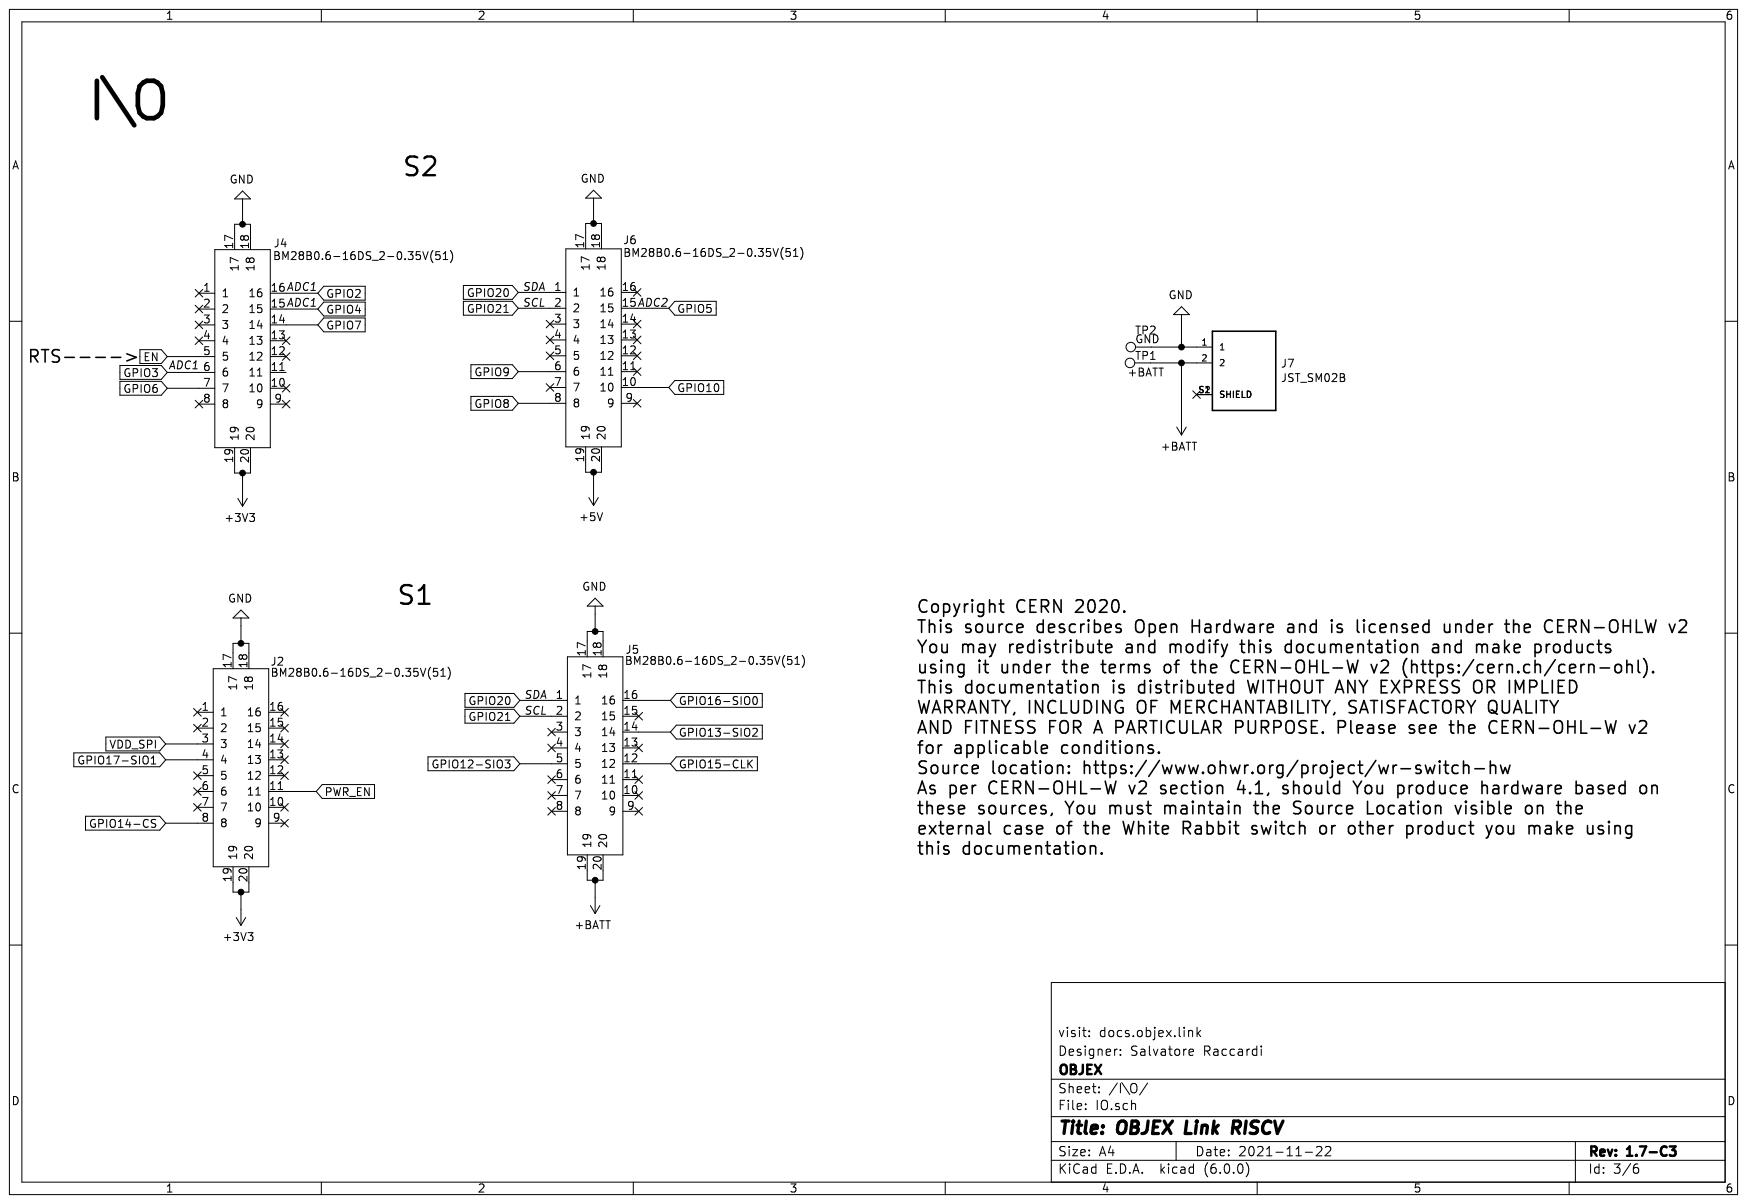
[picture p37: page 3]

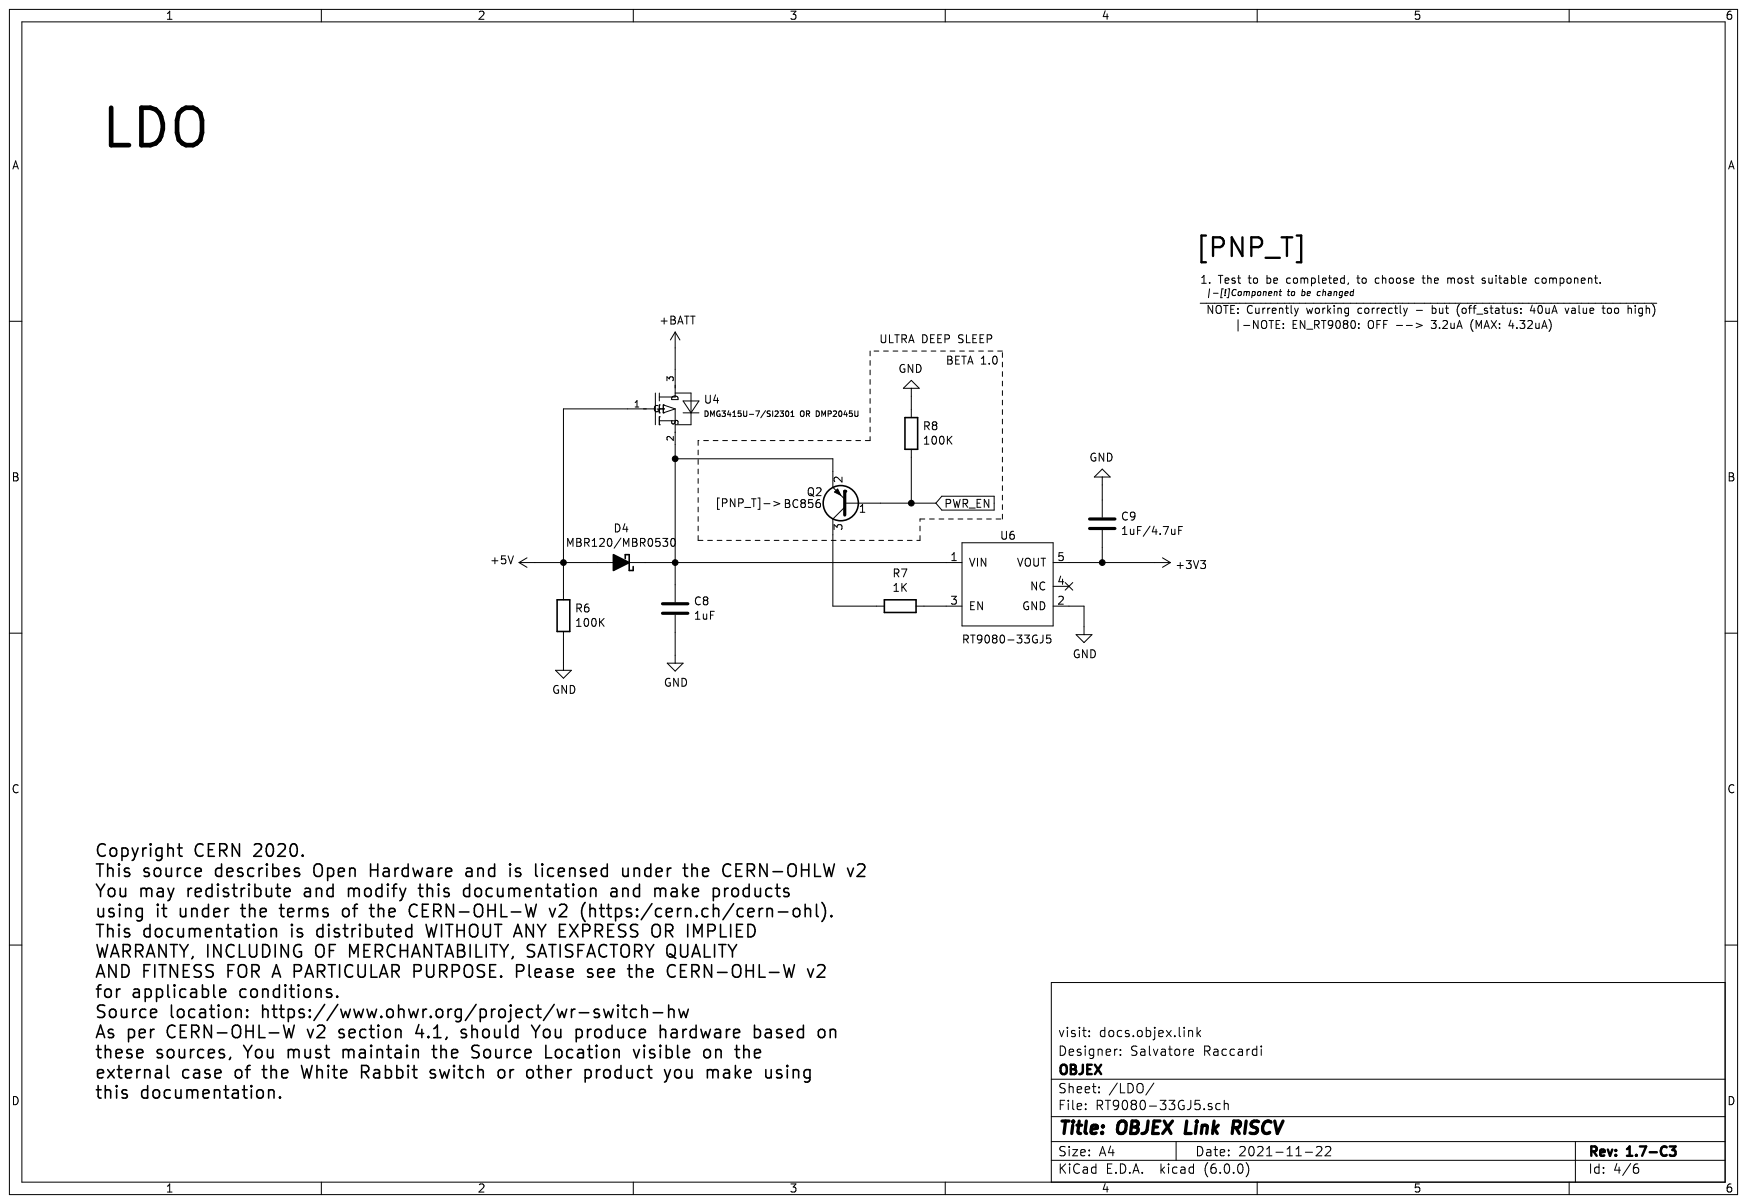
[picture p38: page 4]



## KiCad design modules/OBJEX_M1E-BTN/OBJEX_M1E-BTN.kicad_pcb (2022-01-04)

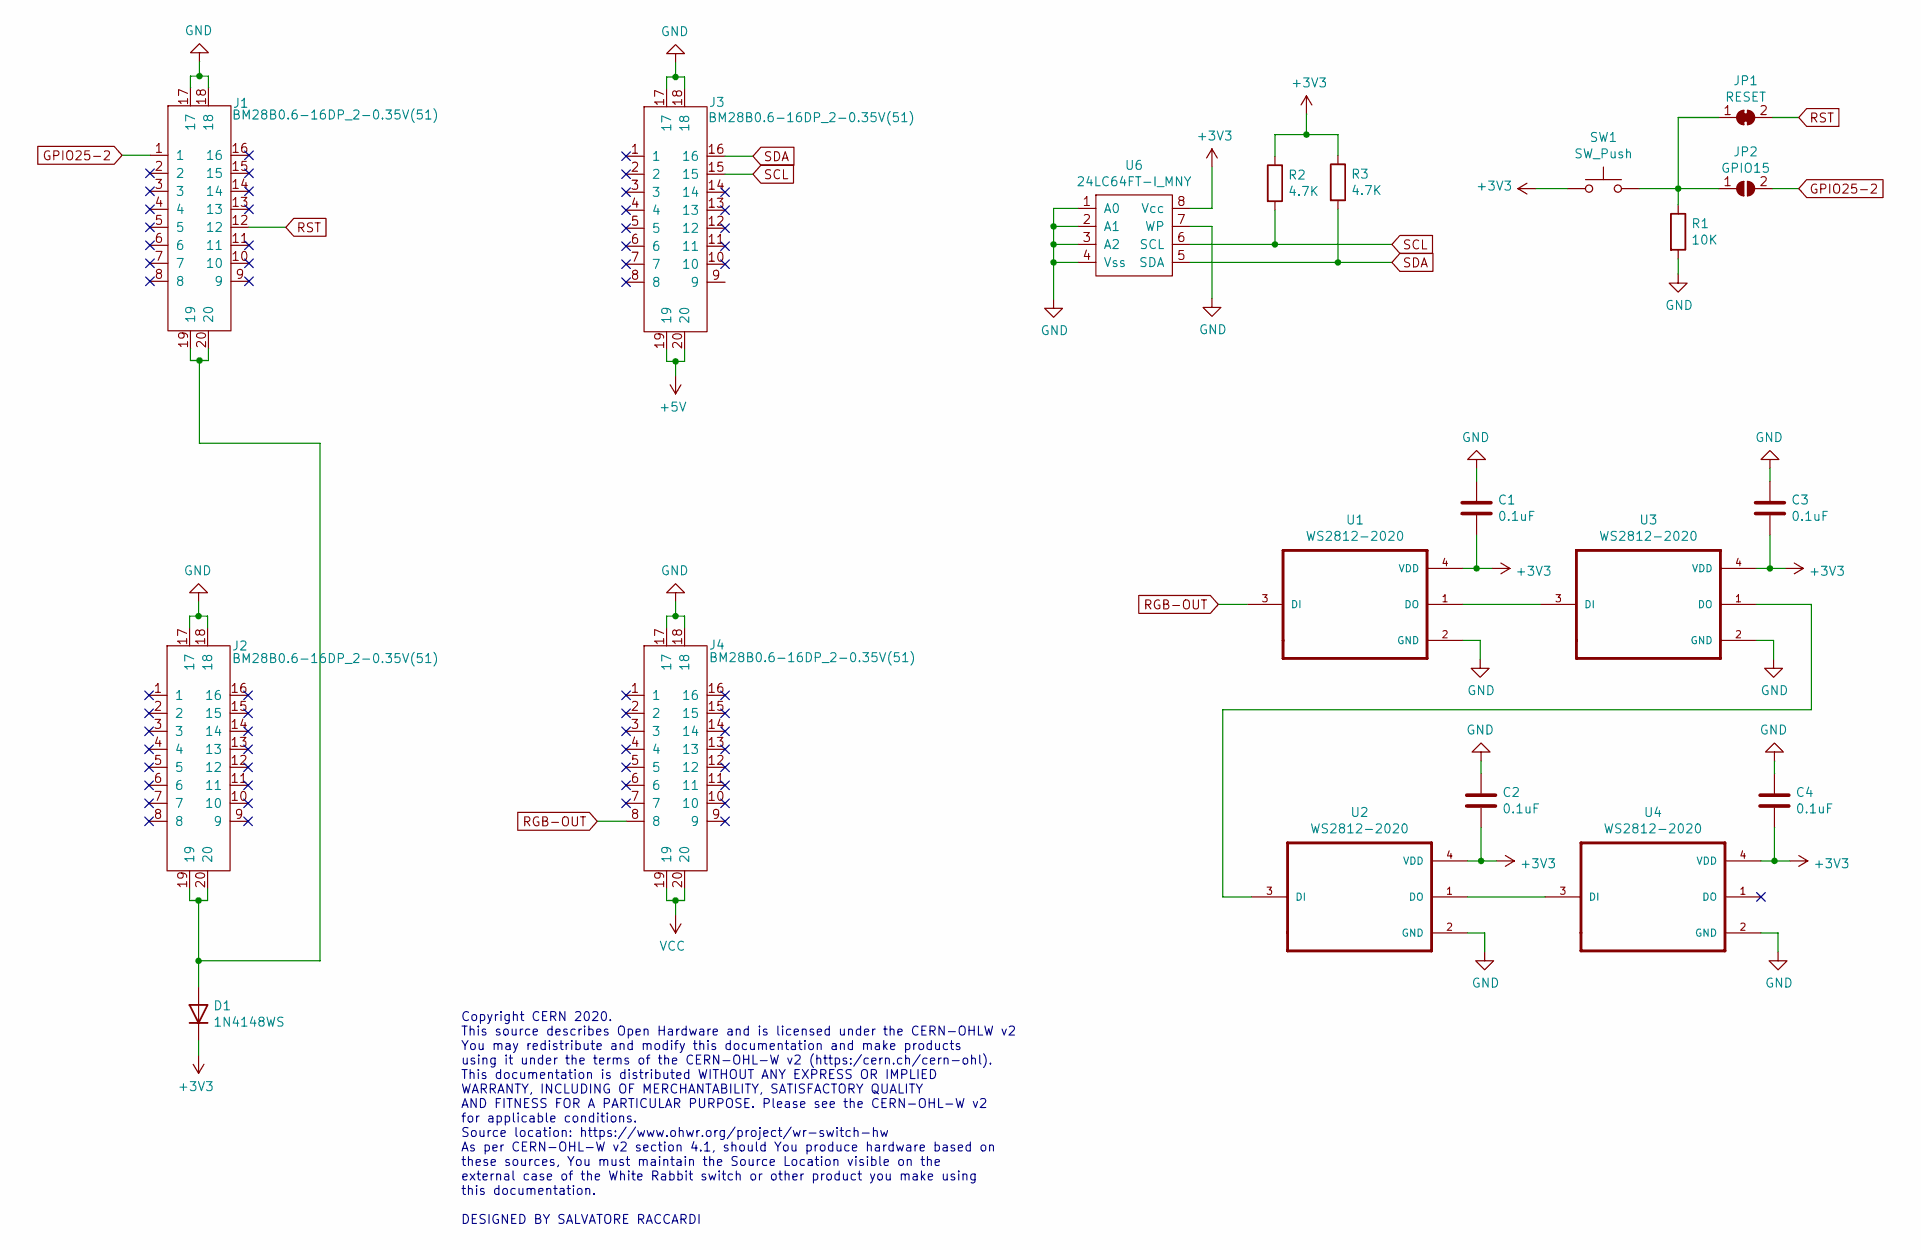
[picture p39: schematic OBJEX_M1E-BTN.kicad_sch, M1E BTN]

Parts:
C1, C2, C3, C4: 0.1uF; C_0402_1005Metric
D1: 1N4148WS; D_SOD-323
J1, J2, J3, J4: BM28B0.6-16DP_2-0.35V(51); BM28B0.6-16DP-2-0.35V(51)
JP1: RESET; SolderJumper-2_P1.3mm_Bridged_Pad1.0x1.5mm
JP2: GPIO15; SolderJumper-2_P1.3mm_Open_Pad1.0x1.5mm
R1: 10K; R_0402_1005Metric
R2, R3: 4.7K; R_0402_1005Metric
SW1: SW_Push; SW_Push_1P1T_NO_CK_PTS125Sx43PSMTR
U1, U2, U3, U4: WS2812-2020; LED_WS2812-2020
U6: 24LC64FT-I_MNY; SON50P200X300X80-8N

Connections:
+3V3: C1.2, C2.2, C3.2, C4.2, D1.1 (K), R2.1, R3.1, SW1.1, U1.4 (VDD), U2.4 (VDD), U3.4 (VDD), U4.4 (VDD), U6.8 (Vcc)
+5V: J3.19, J3.20
GND: C1.1, C2.1, C3.1, C4.1, J1.17, J1.18, J2.17, J2.18, J3.17, J3.18, J4.17, J4.18, R1.2, U1.2 (GND), U2.2 (GND), U3.2 (GND), U4.2 (GND), U6.1 (A0), U6.2 (A1), U6.3 (A2), U6.4 (Vss), U6.7 (WP)
GPIO25-2: J1.1, JP2.2 (B); also elsewhere on the board
unnamed: D1.2 (A), J1.19, J1.20, J2.19, J2.20
unnamed 64: JP1.1 (A), JP2.1 (A), R1.1, SW1.2; also elsewhere on the board
unnamed: U1.1 (DO), U3.3 (DI)
unnamed: U2.1 (DO), U4.3 (DI)
unnamed: U2.3 (DI), U3.1 (DO)
RGB-OUT: J4.8, U1.3 (DI)
RST: J1.12, JP1.2 (B); also elsewhere on the board
SCL: J3.15, R2.2, U6.6 (SCL)
SDA: J3.16, R3.2, U6.5 (SDA)
VCC: J4.19, J4.20

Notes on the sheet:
Copyright CERN 2020. This source describes Open Hardware and is licensed under the CERN-OHLW v2 You may redistribute and modify this documentation and make products using it under the terms of the CERN-OHL-W v2 (https:/cern.ch/cern-ohl). This documentation is distributed WITHOUT ANY EXPRESS OR IMPL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

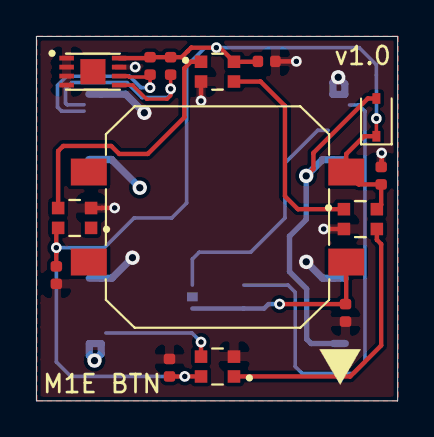
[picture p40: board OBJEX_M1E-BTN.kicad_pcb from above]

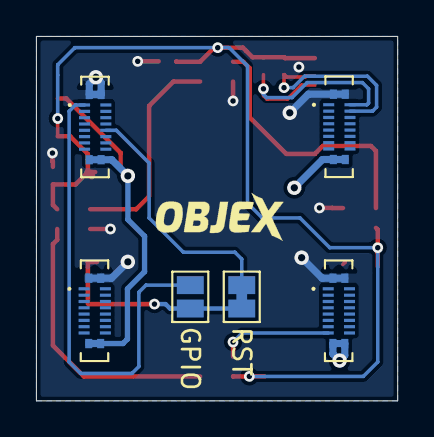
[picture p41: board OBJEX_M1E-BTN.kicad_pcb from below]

Board: 2 copper layers, 20.1 x 20.2 mm, 20 parts (6 on the bottom side), 14 nets.

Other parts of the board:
GPIO: GPIO15; SolderJumper-2_P1.3mm_Open_Pad1.0x1.5mm
RST: RESET; SolderJumper-2_P1.3mm_Bridged_Pad1.0x1.5mm

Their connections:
GPIO25-2: GPIO.2; also elsewhere on the board
unnamed 64: GPIO.1, RST.1; also elsewhere on the board
RST: RST.2; also elsewhere on the board

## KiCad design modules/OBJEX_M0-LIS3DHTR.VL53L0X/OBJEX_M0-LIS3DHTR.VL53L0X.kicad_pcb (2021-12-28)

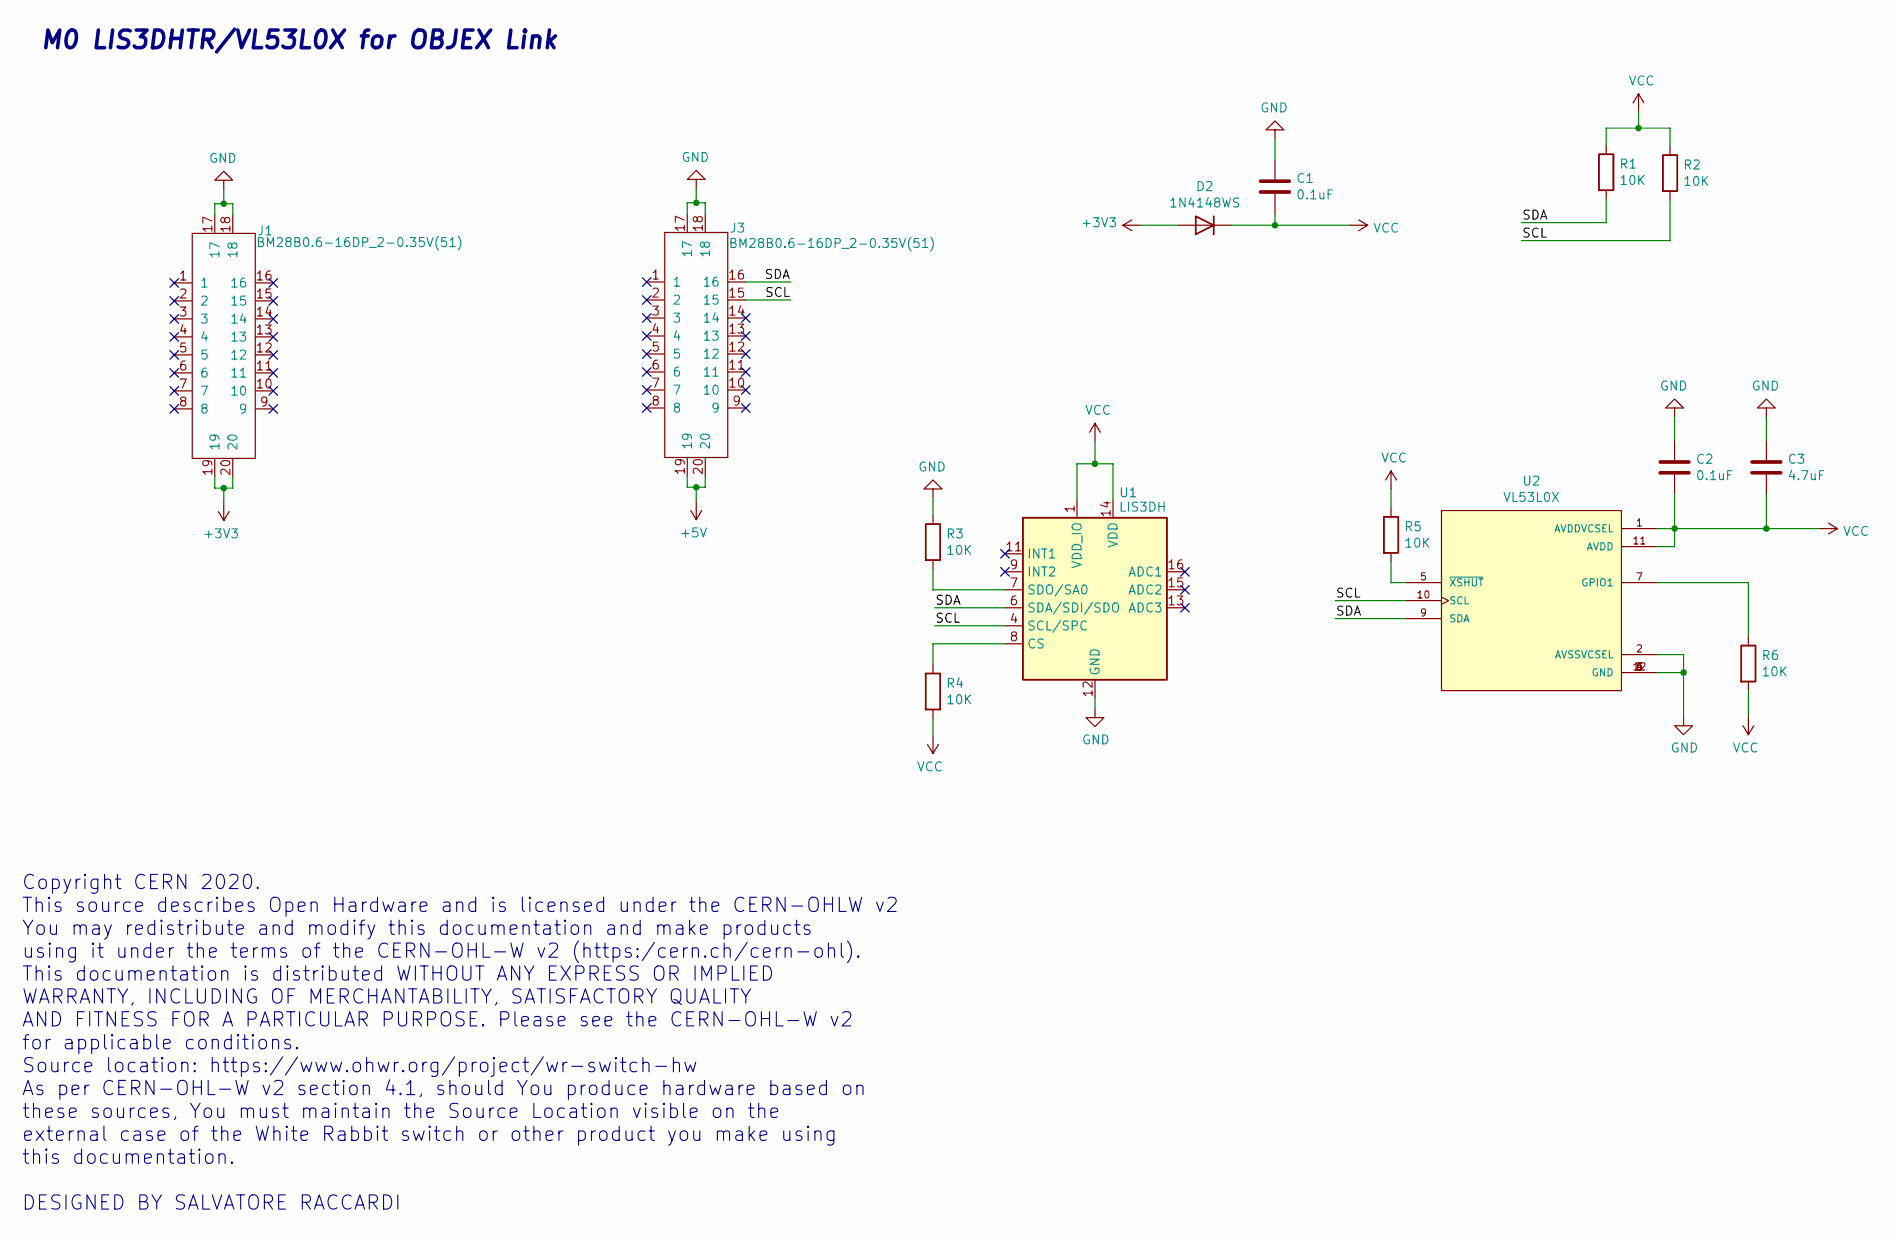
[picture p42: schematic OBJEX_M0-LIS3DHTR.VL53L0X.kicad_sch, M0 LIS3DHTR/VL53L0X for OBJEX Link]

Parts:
C1, C2: 0.1uF; C_0402_1005Metric
C3: 4.7uF; C_0402_1005Metric
D2: 1N4148WS; D_SOD-323
J1, J3: BM28B0.6-16DP_2-0.35V(51); BM28B0.6-16DP-2-0.35V(51)
R1, R2, R3, R4, R5, R6: 10K; R_0402_1005Metric
U1: LIS3DH; LGA-16_3x3mm_P0.5mm_LayoutBorder3x5y
U2: VL53L0X; SENSOR_VL53L0X; PART_REV 1.0

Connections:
+3V3: D2.2 (A), J1.19, J1.20
+5V: J3.19, J3.20
/SCL: J3.15, R2.2, U1.4 (SCL/SPC), U2.10 (SCL)
/SDA: J3.16, R1.2, U1.6 (SDA/SDI/SDO), U2.9 (SDA)
GND: C1.1, C2.1, C3.1, J1.17, J1.18, J3.17, J3.18, R3.1, U1.5 (GND), U1.10 (GND), U1.12 (GND), U2.2 (AVSSVCSEL), U2.3 (GND), U2.4 (GND), U2.6 (GND), U2.12 (GND)
unnamed: R3.2, U1.7 (SDO/SA0)
unnamed: R4.1, U1.8 (CS)
unnamed: R5.2, U2.5 (~XSHUT)
unnamed: R6.1, U2.7 (GPIO1)
VCC: C1.2, C2.2, C3.2, D2.1 (K), R1.1, R2.1, R4.2, R5.1, R6.2, U1.1 (VDD_IO), U1.14 (VDD), U2.1 (AVDDVCSEL), U2.11 (AVDD)

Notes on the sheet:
Copyright CERN 2020. This source describes Open Hardware and is licensed under the CERN-OHLW v2 You may redistribute and modify this documentation and make products using it under the terms of the CERN-OHL-W v2 (https:/cern.ch/cern-ohl). This documentation is distributed WITHOUT ANY EXPRESS OR IMPL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
M0 LIS3DHTR/VL53L0X for OBJEX Link

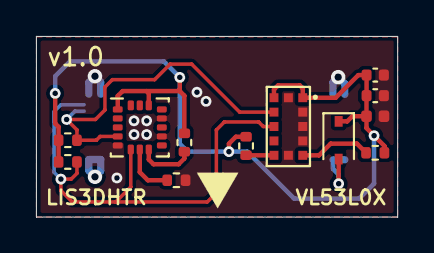
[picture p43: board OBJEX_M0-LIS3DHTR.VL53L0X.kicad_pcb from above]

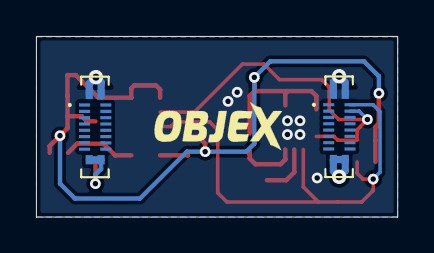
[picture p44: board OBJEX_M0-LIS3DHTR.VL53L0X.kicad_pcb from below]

Board: 2 copper layers, 20.1 x 10.0 mm, 14 parts (2 on the bottom side), 10 nets.

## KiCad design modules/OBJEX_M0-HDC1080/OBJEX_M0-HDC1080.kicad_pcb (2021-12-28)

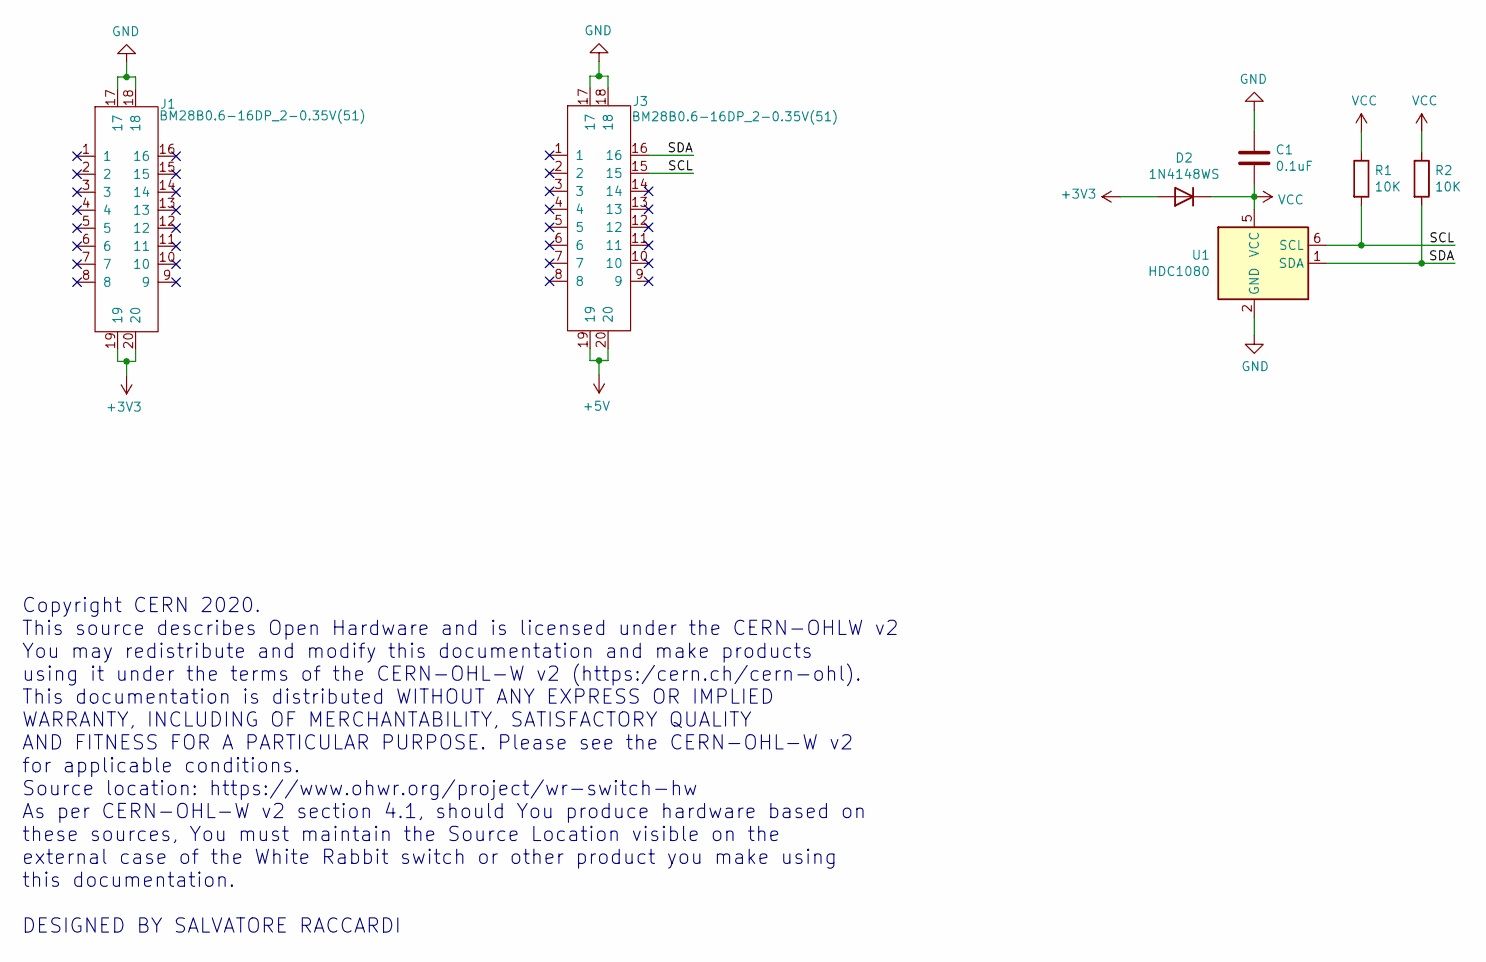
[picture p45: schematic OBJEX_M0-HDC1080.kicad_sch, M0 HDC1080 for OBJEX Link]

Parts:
C1: 0.1uF; C_0402_1005Metric
D2: 1N4148WS; D_SOD-323
J1, J3: BM28B0.6-16DP_2-0.35V(51); BM28B0.6-16DP-2-0.35V(51)
R1, R2: 10K; R_0603_1608Metric
U1: HDC1080; Texas_PWSON-N6

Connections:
+3V3: D2.2 (A), J1.19, J1.20
+5V: J3.19, J3.20
/SCL: J3.15, R1.2, U1.6 (SCL)
/SDA: J3.16, R2.2, U1.1 (SDA)
GND: C1.1, J1.17, J1.18, J3.17, J3.18, U1.2 (GND)
VCC: C1.2, D2.1 (K), R1.1, R2.1, U1.5 (VCC)

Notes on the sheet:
Copyright CERN 2020. This source describes Open Hardware and is licensed under the CERN-OHLW v2 You may redistribute and modify this documentation and make products using it under the terms of the CERN-OHL-W v2 (https:/cern.ch/cern-ohl). This documentation is distributed WITHOUT ANY EXPRESS OR IMPL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

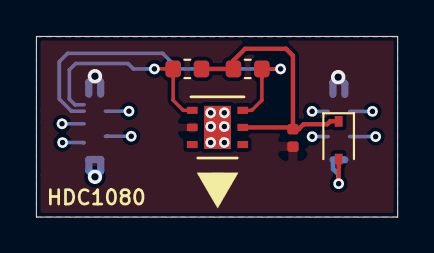
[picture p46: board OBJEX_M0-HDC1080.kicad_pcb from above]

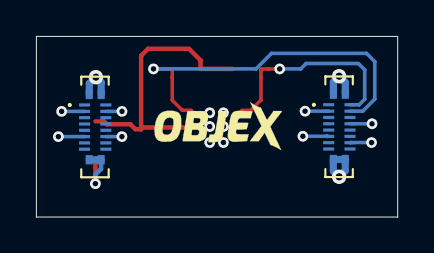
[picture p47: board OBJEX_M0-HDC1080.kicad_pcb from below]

Board: 2 copper layers, 20.1 x 10.0 mm, 7 parts (2 on the bottom side), 6 nets.

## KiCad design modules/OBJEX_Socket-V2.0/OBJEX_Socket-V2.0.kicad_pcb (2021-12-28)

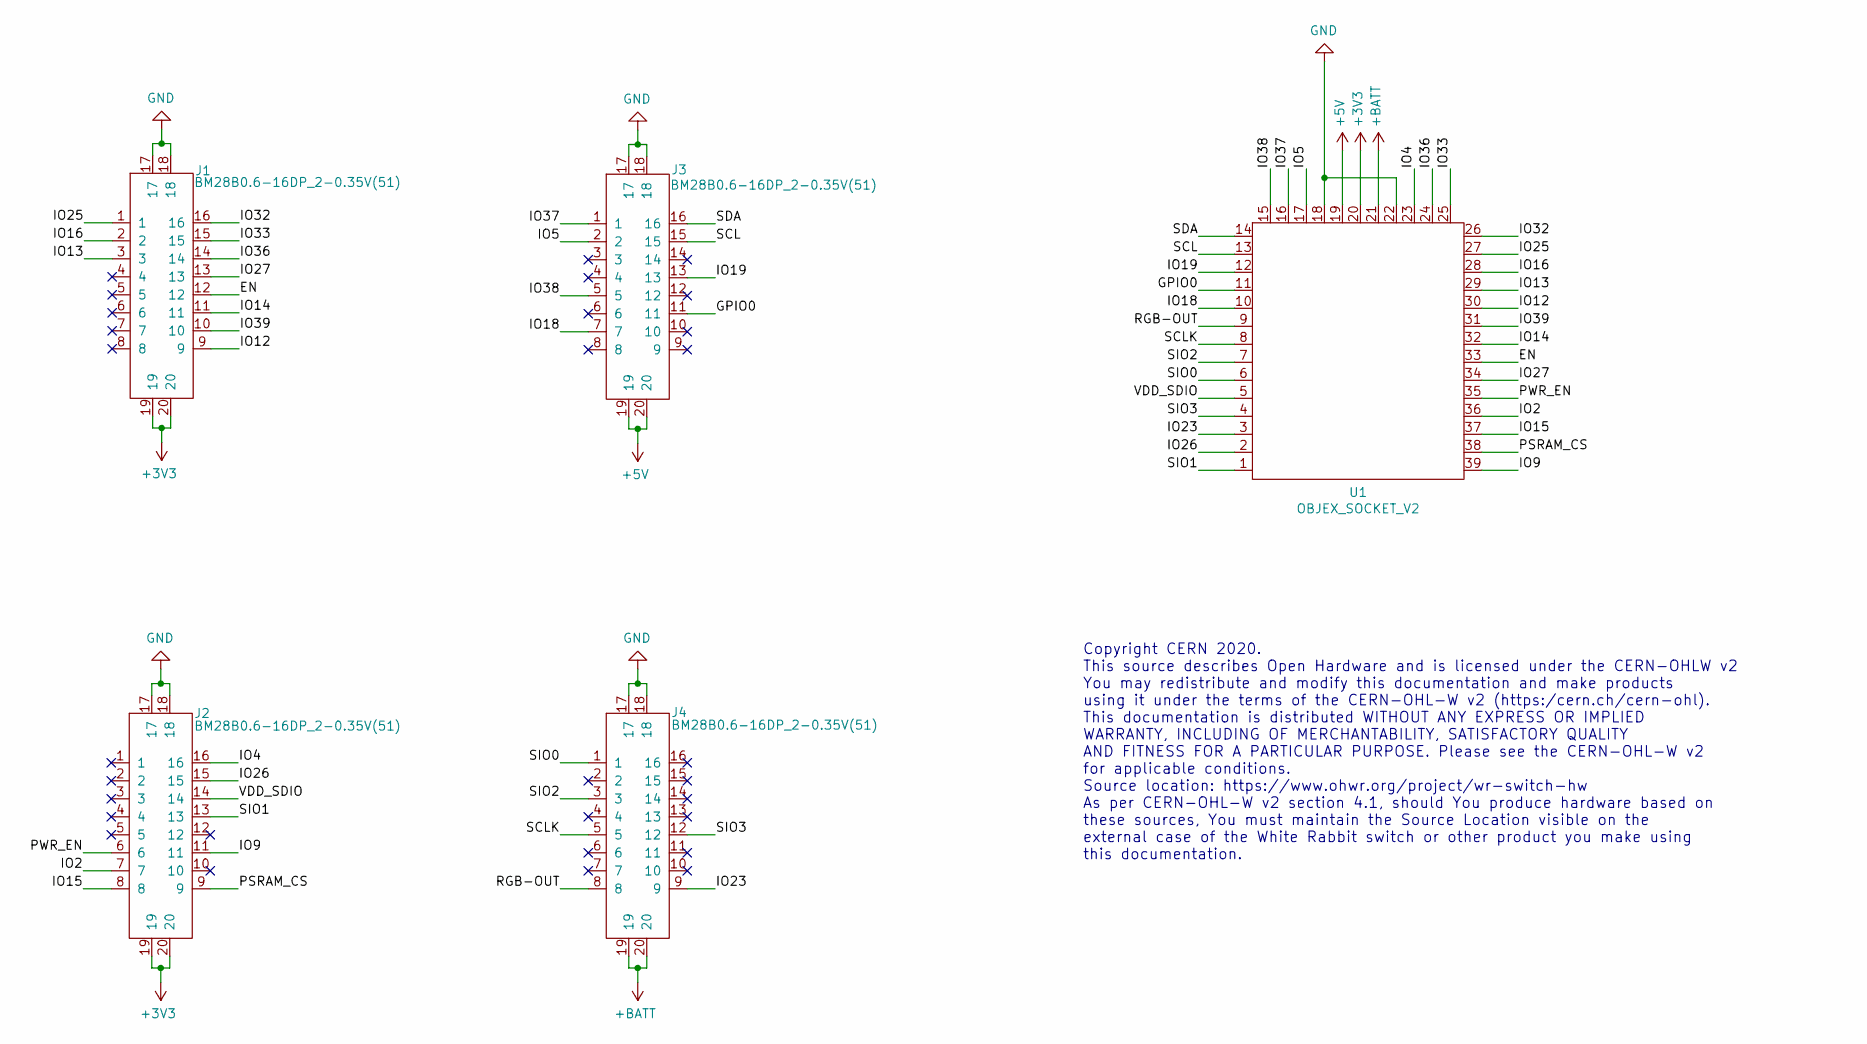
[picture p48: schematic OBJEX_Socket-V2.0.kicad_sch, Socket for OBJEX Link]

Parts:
J1, J2, J3, J4: BM28B0.6-16DP_2-0.35V(51); BM28B0.6-16DP-2-0.35V(51)
U1: OBJEX_SOCKET_V2; OBJEX_Link-Castellated

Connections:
+3V3: J1.19, J1.20, J2.19, J2.20, U1.20
+5V: J3.19, J3.20, U1.19
+BATT: J4.19, J4.20, U1.21
/EN: J1.12, U1.33
/GPIO0: J3.11, U1.11
/IO2: J2.7, U1.36
/IO4: J2.16, U1.23
/IO5: J3.2, U1.17
/IO9: J2.11, U1.39
/IO12: J1.9, U1.30
/IO13: J1.3, U1.29
/IO14: J1.11, U1.32
/IO15: J2.8, U1.37
/IO16: J1.2, U1.28
/IO18: J3.7, U1.10
/IO19: J3.13, U1.12
/IO23: J4.9, U1.3
/IO25: J1.1, U1.27
/IO26: J2.15, U1.2
/IO27: J1.13, U1.34
/IO32: J1.16, U1.26
/IO33: J1.15, U1.25
/IO36: J1.14, U1.24
/IO37: J3.1, U1.16
/IO38: J3.5, U1.15
/IO39: J1.10, U1.31
/PSRAM_CS: J2.9, U1.38
/PWR_EN: J2.6, U1.35
/RGB-OUT: J4.8, U1.9
/SCL: J3.15, U1.13
/SCLK: J4.5, U1.8
/SDA: J3.16, U1.14
/SIO0: J4.1, U1.6
/SIO1: J2.13, U1.1
/SIO2: J4.3, U1.7
/SIO3: J4.12, U1.4
/VDD_SDIO: J2.14, U1.5
GND: J1.17, J1.18, J2.17, J2.18, J3.17, J3.18, J4.17, J4.18, U1.18, U1.22

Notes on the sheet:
Copyright CERN 2020. This source describes Open Hardware and is licensed under the CERN-OHLW v2 You may redistribute and modify this documentation and make products using it under the terms of the CERN-OHL-W v2 (https:/cern.ch/cern-ohl). This documentation is distributed WITHOUT ANY EXPRESS OR IMPL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

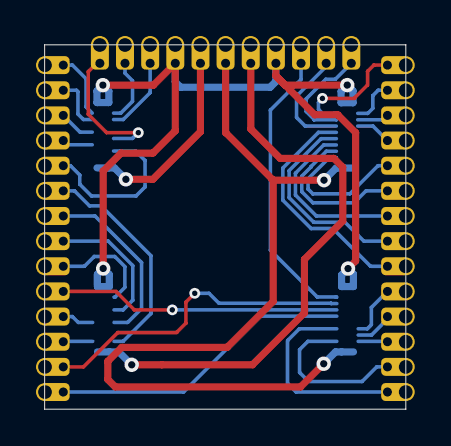
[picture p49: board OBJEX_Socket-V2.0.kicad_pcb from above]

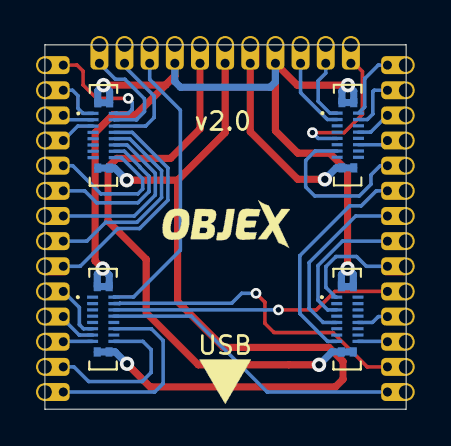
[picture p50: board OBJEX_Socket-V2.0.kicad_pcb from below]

Board: 2 copper layers, 20.1 x 20.2 mm, 5 parts (4 on the bottom side), 38 nets.

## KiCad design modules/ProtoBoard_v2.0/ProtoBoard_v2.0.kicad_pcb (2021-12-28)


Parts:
J1, J2, J3, J4: Conn_01x10; PinHeader_1x10_P2.54mm_Vertical
U1: OBJEX_SOCKET_V2-pads; OBJEX_Link-Pads

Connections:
+3V3: J2.1, J3.10, U1.20 (3V3)
+5V: J2.2, U1.19 (5V)
+BATT: J3.9, U1.21 (BATT)
/EN: J4.7, U1.33 (EN)
/GPIO0: J1.3, U1.11 (GPIO0)
/IO2: J4.4, U1.36 (IO2)
/IO4: J2.8, U1.23 (IO4)
/IO5: J2.3, U1.17 (IO5)
/IO9: J4.1, U1.39 (IO9)
/IO12: J3.3, U1.30 (IO12)
/IO13: J3.4, U1.29 (IO13)
/IO14: J3.1, U1.32 (IO14)
/IO15: J4.3, U1.37 (IO15)
/IO16: J3.5, U1.28 (IO16)
/IO18: J2.7, U1.10 (IO18)
/IO19: J2.6, U1.12 (IO19)
/IO23: J1.8, U1.3 (IO23)
/IO25: J3.6, U1.27 (IO25)
/IO26: J1.9, U1.2 (IO26)
/IO27: J4.6, U1.34 (IO27)
/IO32: J3.7, U1.26 (IO32)
/IO33: J3.8, U1.25 (IO33)
/IO36: J4.5, U1.24 (IO36)
/IO37: J4.8, U1.16 (IO37)
/IO38: J4.9, U1.15 (IO38)
/IO39: J3.2, U1.31 (IO39)
/PSRAM: J4.2, U1.38 (PSRAM_CS)
/PWR_EN: J1.2, U1.35 (!PWR_EN)
/RGB-OUT: J1.6, U1.9 (RGB_OUT)
/SCL: J2.5, U1.13 (SCL)
/SCLK: J2.10, U1.8 (SCLK)
/SDA: J2.4, U1.14 (SDA)
/SIO0: J1.5, U1.6 (SIO0)
/SIO1: J1.10, U1.1 (SIO1)
/SIO2: J1.4, U1.7 (SIO2)
/SIO3: J1.7, U1.4 (SIO3~)
/VDD_SDIO: J2.9, U1.5 (VDD_SDIO)
GND: J1.1, J4.10, U1.18 (GND), U1.22 (GND)

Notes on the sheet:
Copyright CERN 2020. This source describes Open Hardware and is licensed under the CERN-OHLW v2 You may redistribute and modify this documentation and make products using it under the terms of the CERN-OHL-W v2 (https:/cern.ch/cern-ohl). This documentation is distributed WITHOUT ANY EXPRESS OR IMPL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


Board: 2 copper layers, 62.5 x 26.7 mm, 5 parts (0 on the bottom side), 38 nets.

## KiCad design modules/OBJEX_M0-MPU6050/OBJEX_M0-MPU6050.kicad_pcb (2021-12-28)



Board: 2 copper layers, 20.1 x 10.0 mm, 10 parts (2 on the bottom side), 9 nets.

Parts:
C1: 2200pF; C_0603_1608Metric
C2, C4: 0.1uF; C_0402_1005Metric
C3: 0.01uF; C_0402_1005Metric
J1, J3: BM28B0.6-16DP_2-0.35V(51); BM28B0.6-16DP-2-0.35V(51)
R1, R2, R3: 4.7K; R_0402_1005Metric
U1: MPU6050; IC_MPU6050

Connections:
+3V3: C3.1, C4.1, J1.19, J1.20, R1.1, R2.1, U1.8, U1.13
+5V: J3.19, J3.20
/SCL: J3.15, R2.2, U1.23
/SDA: J3.16, R1.2, U1.24
GND: C1.2, C2.2, C3.2, C4.2, J1.17, J1.18, J3.17, J3.18, R3.1, U1.1, U1.11, U1.18
unnamed: C1.1, U1.20
unnamed: C2.1, U1.10
unnamed: R3.2, U1.9
unnamed: U1.19, U1.21

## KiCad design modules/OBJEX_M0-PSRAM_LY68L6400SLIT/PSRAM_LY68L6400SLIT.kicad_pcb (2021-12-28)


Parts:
C1: 0.1uF; C_0402_1005Metric
D2: 1N4148WS; D_SOD-323
J1, J3: BM28B0.6-16DP_2-0.35V(51); BM28B0.6-16DP-2-0.35V(51)
U1: ESP-PSRAM32; SOIC-8_3.9x4.9mm_P1.27mm

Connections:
+3V3: J1.19, J1.20
+BATT: J3.19, J3.20
/PSRAM_CS: J1.9, U1.1 (~CE)
/SCLK: J3.5, U1.6 (SCLK)
/SIO0: J3.1, U1.5 (SI/SIO)
/SIO1: J1.13, U1.2 (SO/SIO)
/SIO2: J3.3, U1.3 (SIO2)
/SIO3: J3.12, U1.7 (SIO3)
GND: C1.1, J1.17, J1.18, J3.17, J3.18, U1.4 (VSS)
VCC: C1.2, D2.1 (K), U1.8 (VCC)
VDD: D2.2 (A), J1.14

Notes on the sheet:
Copyright CERN 2020. This source describes Open Hardware and is licensed under the CERN-OHLW v2 You may redistribute and modify this documentation and make products using it under the terms of the CERN-OHL-W v2 (https:/cern.ch/cern-ohl). This documentation is distributed WITHOUT ANY EXPRESS OR IMPL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
ONLY COMPATIBLE FOR S1 SLOT
M0 PSRAM_LY68L6400SLIT for OBJEX Link



Board: 2 copper layers, 20.1 x 10.0 mm, 5 parts (2 on the bottom side), 11 nets.

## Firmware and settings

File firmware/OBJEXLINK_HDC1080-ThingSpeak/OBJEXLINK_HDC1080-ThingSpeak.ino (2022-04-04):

RTC_DATA_ATTR int bootCount = 0;                      // for deepsleep
#include <driver/adc.h>
#include <EEPROM.h>
#include <WiFi.h>
#include "ThingSpeak.h"
#include "ClosedCube_HDC1080.h"

const char* ssid = "Raccardi";                        // WIFI_SSID 
const char* password = "raccardi2016";                // WIFI_PASS 

WiFiClient  client;
ClosedCube_HDC1080 hdc1080;

unsigned long myChannelNumber = 1;                     // ThingSpeak Channel number
const char * myWriteAPIKey = "KB9JMEVB4GJPMNED";       // ThingSpeak API Key

float temperatureC, humidity;
float batteryLVL;

void setup() {
  Serial.begin(115200);                                 // Start serial
  EEPROM.begin(1);
  adc1_config_width(ADC_WIDTH_BIT_12);
  adc1_config_channel_atten(ADC1_CHANNEL_0, ADC_ATTEN_DB_11);
  adc1_config_channel_atten(ADC1_CHANNEL_3, ADC_ATTEN_DB_11);
  adc1_config_channel_atten(ADC1_CHANNEL_4, ADC_ATTEN_DB_11);
  
  ++bootCount;                                          // BootCount for deepsleep
  esp_sleep_enable_timer_wakeup(900 * 1000000);         // 300sec->5min
  hdc1080.beginCustom(0x40, 20, 21);                    // ONLY FOR OBJEX Link v1.7-C3 RISCV
  //hdc1080.beginCustom(0x40, 18, 19);                  // ONLY FOR OBJEX Link v1.6-C3 RISCV
  //hdc1080.begin(0x40);                                  // OBJEX Link v1.0/1.5/1.6

  // every 12h -> auto restart
  if(EEPROM.read(0) < 48){
    EEPROM.write(0, EEPROM.read(0) + 1);
    EEPROM.commit();
  }else{
    EEPROM.write(0, 1);
    EEPROM.commit();
    ESP.restart();
  }

  WiFi.mode(WIFI_STA);                                  // WiFi
  WiFi.begin(ssid, password); 
  while(WiFi.status() != WL_CONNECTED){  
    Serial.print(".");
    delay(500);     
  } 
  Serial.println("");
  Serial.print("Connected to ");
  Serial.println(ssid);
  
  ThingSpeak.begin(client);                              // Init thingspeak
}

void loop() {

    temperatureC = hdc1080.readTemperature();
    humidity = hdc1080.readHumidity();
    
    int battery = adc1_get_raw((adc1_channel_t)3);
    batteryLVL = (battery / (4096 / 3.7)) / 0.64; // ADC Value --> voltage
    
    Serial.print("Temperature (ºC)");
    Serial.println(temperatureC);
    Serial.print("Humidity (%)");
    Serial.println(humidity);
    Serial.print("batteryLVL (value)");
    Serial.println(batteryLVL);
   
    ThingSpeak.setField(1, temperatureC);
    ThingSpeak.setField(2, humidity);
    ThingSpeak.setField(3, batteryLVL);
    
    int x = ThingSpeak.writeFields(myChannelNumber, myWriteAPIKey);

    if(x == 200){
      Serial.println("Channel update successful.");
    }
    else{
      Serial.println("Problem updating channel. HTTP error code " + String(x));
    }
  
  Serial.println("OBJEX Link - Sleep now!");
  Serial.flush(); 
  esp_deep_sleep_start();
}

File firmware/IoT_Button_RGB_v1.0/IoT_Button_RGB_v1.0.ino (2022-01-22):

RTC_DATA_ATTR int boot = 0;

#include <Adafruit_NeoPixel.h>
#define LED_PIN    23
#define LED_COUNT 5
Adafruit_NeoPixel leds(LED_COUNT, LED_PIN, NEO_GRB + NEO_KHZ800);


void setup() {
  Serial.begin(115200);
  ++boot;
  // 0x8000 => 2^15 in hex => GPIO15
  //esp_sleep_enable_ext1_wakeup(0x8000,ESP_EXT1_WAKEUP_ANY_HIGH); 
  esp_sleep_enable_ext0_wakeup(GPIO_NUM_25, 1); //OBJEX LINK v1.6
  //esp_deep_sleep_enable_gpio_wakeup(0x0004,ESP_GPIO_WAKEUP_GPIO_HIGH); //RISCV: GPIO2 --> ProtoBoard(25)

  delay(500);
  // WS2812B-2020 init
 
  leds.begin(); 
  leds.setBrightness(0);          
  leds.show();
}


void loop() {  
  rgb(250);   
  Serial.println("Sleep!");
  esp_deep_sleep_start();
}

void rgb(int wait){
  leds.setBrightness(50);
  for(int i = 0; i < leds.numPixels(); i++){
     leds.setPixelColor(i, 0, 255, 0);
     leds.show();
     delay(wait); 
  }
  leds.setBrightness(0); 
  leds.show();  
}

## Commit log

2021-04-03 beta1.0 3D Case
    [BTN-Top.stl, HDC1080-Top.stl, Master.stl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]
2021-09-26 add new cover v2.1
    [V2.1coverOBJEXLink.stl]
2021-11-04 add: docs boards
2021-11-04 General update for new boards/modules
    [BM28-16DP.stp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]
2021-11-18 add: all schematics
2021-11-18 FIX: schematics
2021-12-10 Add: PSRAM Module v1.0
    [PSRAM_LY68L6400SLIT.kicad_pcb, PSRAM_LY68L6400SLIT.sch]
2021-12-15 add: LIS3DHTR-VL53L0X Module
    [OBJEX_M0-LIS3DHTR.VL53L0X.kicad_pcb, OBJEX_M0-LIS3DHTR.VL53L0X.sch]
2021-12-28 Update KiCad 6.0.0
    [OBJEX_M0-HDC1080.kicad_pcb, OBJEX_M0-HDC1080.kicad_sch, OBJEX_M0-LIS3DHTR.VL53L0X.kicad_pcb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]
2022-01-04 Add: M1E IoT BTN Module
    [OBJEX_M1E-BTN.kicad_pcb, OBJEX_M1E-BTN.kicad_sch, OBJEX_M1E-BTN.sch]
2022-03-14 add new board: OBJEX Link v1.6_RF
2022-04-04 Add: CAD file for Socket v2.0
